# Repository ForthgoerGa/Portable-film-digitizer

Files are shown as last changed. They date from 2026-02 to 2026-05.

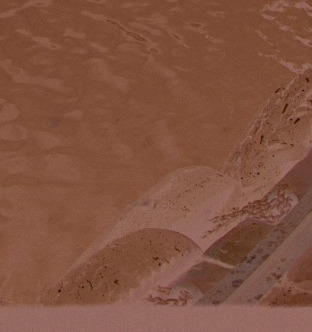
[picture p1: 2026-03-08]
Image_integration&Post_Processing/Negative_example/norway_split_40_overlap/tile_r05_c06_38.png

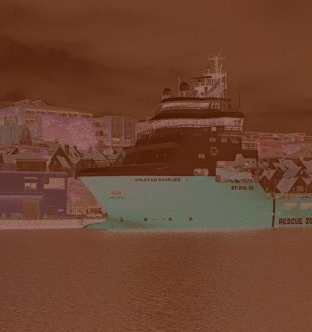
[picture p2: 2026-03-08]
Image_integration&Post_Processing/Negative_example/norway_split_40_overlap/tile_r03_c04_20.png

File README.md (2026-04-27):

# Portable Multi-Format Film Digitization System

ECE 445 coursework design project repository for hardware/firmware/software development and lab notebook tracking.

屏幕截图 2026-04-27 164834

Results:

2026_04_27_00_14_IMG_3069

## System Block Diagram
This block diagram shows the general system design and how the power subsystem, control unit, and imaging subsystem are connected.

Gemini_Generated_Image_8ml5k58ml5k58ml5

## Project Goal
Build a portable, battery-powered film digitizer that supports:
- 35mm negatives/slides (transmissive)
- 120 medium format film (transmissive)
- Instax Mini prints (reflective)

The system captures a raw frame, uploads via Wi-Fi, performs cloud processing (negative inversion + enhancement), and returns a social-media-ready image.

## Problem
Current film digitization workflows are either:
- expensive and slow (professional scanners),
- fast but complex and non-portable (DSLR scanning rigs),
- or outsourced with long turnaround times (lab services).

This project targets a one-click workflow with fast turnaround and practical portability.

## Solution Overview
An STM32-based control system coordinates:
- dual-mode illumination (backlight for transmissive film, angled front light for reflective media),
- high-resolution sensor capture,
- network upload to cloud backend,
- return of processed output to a mobile device.

## Major Subsystems
1. **Power Supply and Management (PCB)**  
   Li-Ion battery pack, charging/protection (BMS), regulated rails for logic and LEDs.
2. **MCU and Control (STM32F4/H7)**  
   UI handling, capture sequencing, sensor interface, and network orchestration.
3. **Dual-Mode Illumination**  
   High-CRI transmissive array + glare-controlled reflective array, PWM-controlled.
4. **Cloud Processing Pipeline (Python)**  
   Negative inversion (orange mask handling), denoising, sharpening, and API response.

## Optical Stack (Current Plan)
- Sensor: Raspberry Pi HQ Camera (IMX477)
- Lens: 25mm f/1.4 C-mount lens
- Extension: 10mm C-mount tube for macro working distance (~8.5 cm)

## Success Criteria
- Resolution: at least `3840 x 2160` output.
- Speed: under `15 seconds` from capture press to phone delivery (stable network).
- Versatility: works with 35mm, 120, and Instax Mini.
- Portability: under `30 cm x 20 cm x 15 cm`, under `1.5 kg`.
- Battery: at least `360 shots` (~10 rolls) per charge.

## Repository Layout
```text
hardware/              PCB + mechanical design files
firmware/              STM32 firmware and drivers
software/              Cloud/image-processing code and APIs
docs/                  Specs, architecture, plans, reports
lab-notebook/          Dated engineering logs
```

## Lab Notebook Workflow
1. Add one file per workday in `lab-notebook/` using `YYYY-MM-DD.md`.
2. Record decisions, measurements, failures, and next steps.
3. Include links to commits, issues, and test data where possible.
4. Use `lab-notebook/TEMPLATE.md` for consistency.

## Quick Start (Local)
```powershell
git init -b main
git add .
git commit -m "Initial project scaffold"
```

## Running the Software

### Web Inspection Server (PC)
Runs the FastAPI server with the web UI for scan control and image review:
```bash
cd software && python server.py
# FastAPI at http://localhost:8000, web UI at http://localhost:8000/web/
```

### Raspberry Pi Camera Server
Streams a live MJPEG preview, triggers captures, and forwards to the PC pipeline:
```bash
# On the Raspberry Pi:
python3 software/rpi_camera_server.py [--port 8080] [--button-pin 17] [--pc-host <PC_IP>]
# Web UI at http://<pi-ip>:8080/
```

### Agentic Post-Processing Pipeline
Runs the Gemini-powered agent loop (classify → process → evaluate → refine):
```bash
cd Agentic_Post_Processing
python orchestrator.py --input-dir data --output-dir output --max-iter 2
```
Requires a `.env` file with `GEMINI_API_KEY` (see `.env.example`). Falls back to heuristics automatically if the key is absent.

### Raw Negative Pipeline (direct)
```bash
python software/processing/negative_pipeline.py \
  --tiles-dir "Image_integration&Post_Processing/Negative_example/norway_split_40_overlap" \
  --output-dir "Image_integration&Post_Processing/output_demo" \
  --wb-clip-percent 0.5
```

## GitHub Setup
See `docs/github-setup.md` for:
- creating the remote repo,
- pushing `main`,
- inviting collaborator `Allannn-sudo`.

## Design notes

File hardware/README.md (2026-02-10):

# Hardware

Hardware design workspace.

## Contents
- `pcb/`: schematics, layout, BOM, manufacturing files
- `mechanical/`: enclosure/chamber CAD and drawings

## Suggested Milestones
1. Define system-level electrical interfaces.
2. Complete power + illumination prototype board.
3. Validate thermal behavior and uniformity.
4. Finalize integrated revision for demo.

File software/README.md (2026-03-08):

# Software

Cloud and processing software.

## Responsibilities
- Receive uploaded raw captures
- Invert color negatives and remove orange mask
- Denoise/sharpen and apply color look
- Return processed image URL/API response

## Suggested structure
- `cloud/`
- `api/`
- `processing/`
- `tests/`

## Current demo
- `processing/negative_pipeline.py`: stitches overlapping film tiles, then restores color with white balance, contrast/tone recovery, and selective cast suppression.
- `server.py` + `web/`: FastAPI + web UI flow where `Start Scan` processes sample fractions, shows tile grid, stitched raw image, and white-balanced output.

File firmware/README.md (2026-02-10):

# Firmware

STM32 firmware workspace.

## Responsibilities
- Capture sequencing and timing
- LED illumination control (PWM)
- Sensor interface and frame acquisition
- Wi-Fi module communication
- UI handling (buttons + OLED)

## Suggested structure
- `src/`
- `include/`
- `drivers/`
- `tests/`

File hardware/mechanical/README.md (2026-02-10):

# Mechanical

Place enclosure and optical chamber models here.

## Suggested structure
- `cad/`
- `drawings/`
- `prints/`
- `assembly-notes/`

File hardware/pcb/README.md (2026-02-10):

# PCB

Place PCB design files here.

## Suggested structure
- `schematics/`
- `layout/`
- `bom/`
- `gerbers/`
- `test-results/`

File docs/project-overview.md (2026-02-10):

# Project Overview

## Summary
Portable film digitization device using an STM32 MCU, dual-mode illumination, and a cloud processing pipeline to deliver fast, social-media-ready images from 35mm, 120, and Instax formats.

## Objectives
- Provide a one-click digitization workflow.
- Achieve 4K output with acceptable dynamic range for common color negative film.
- Maintain portability and low power consumption.

## Scope
- Hardware platform (power, illumination, controller, sensor integration)
- Firmware control and capture pipeline
- Cloud processing prototype for image enhancement
- Lab notebook documentation for engineering decisions

## Key Risks
- Illumination uniformity and glare control
- End-to-end latency under variable network conditions
- Reliable negative inversion across different film stocks

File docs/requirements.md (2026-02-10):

# Requirements and Verification

## Functional Requirements
1. Capture and process at least three formats: 35mm, 120, Instax Mini.
2. Produce output image at or above 3840x2160.
3. Complete capture-to-delivery under 15 seconds on stable Wi-Fi.
4. Run from battery power without external adapter during use.
5. Provide user feedback for idle/capture/upload/success/error states.

## Physical Requirements
1. Overall size under 30 cm x 20 cm x 15 cm.
2. Mass under 1.5 kg.
3. Film carrier insertion must be tool-free.

## Power Requirements
1. Support at least 360 captures on one full charge.
2. Maintain stable illumination intensity during low battery.

## Verification Plan
- Resolution: test chart capture and measured pixel dimensions.
- Dynamic range: evaluate shadow/highlight retention on Portra 400 negative sample.
- Latency: timestamp each stage over at least 30 trials.
- Versatility: run end-to-end workflow for all three formats.
- Battery: execute continuous capture run to count total completed shots.

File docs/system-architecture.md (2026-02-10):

# System Architecture

## Block-Level Flow
1. User inserts film carrier and selects mode (or auto-detect).
2. STM32 configures illumination profile and sensor capture parameters.
3. Sensor captures raw frame.
4. Wi-Fi module uploads frame + metadata to cloud endpoint.
5. Cloud function processes image and returns result URL.
6. Device/app displays completion status.

## Hardware Subsystems
- Power subsystem: Li-Ion battery, charger/protection, logic and LED rails.
- Control subsystem: STM32, UI inputs, OLED status output.
- Imaging subsystem: CMOS sensor and lens stack.
- Illumination subsystem: transmissive + reflective arrays, PWM-driven.
- Networking subsystem: Wi-Fi module interface.

## Software Subsystems
- Embedded firmware state machine for capture orchestration.
- Cloud API receiver and storage.
- Image processing pipeline (inversion, denoise, grade).
- Optional mobile/web client for preview and download.

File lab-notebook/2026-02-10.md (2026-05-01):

# 2026-02-10

## Project Kickoff
- Defined problem: portable, multi-format film digitizer with instant cloud-processed output.
- Selected STM32 MCU + IMX477 sensor with dual-mode illumination system.
- Chosen optical stack: 25mm C-mount lens + 10mm extension for macro distance.

## Next Steps
- Draft high-level block diagram.
- Define power budget and battery capacity.
- Identify LED array requirements (CRI, intensity, diffusion stack).

## High-Level Requirements (HLRs)
- 1. Resolution & Quality: The system must be capable of digitizing various film formats (35mm, 120 medium format, and Instax), outputting images with a minimum resolution of 4K (3840x2160). It must possess sufficient dynamic range to recover shadow and highlight details from the negatives. (Design Basis: Utilizing the Pi HQ Camera + 25mm lens + extension tube macro solution + stitching scan technology.)
- 2. Portability & Autonomy: The system must be a self-contained, portable device with physical dimensions limited to 30cm x 20cm x 15cm and a weight of less than 1.5kg. It must be powered by a lithium-ion battery, capable of scanning at least 10 rolls of film (360 exposures) on a single charge.
- 3. Speed & Automation: The system must implement automated lighting adjustment, film transport, and image capture workflows. The total duration from the moment the user presses "Capture" to receiving the processed digital image (via Wi-Fi upload and processing) must not exceed 15 seconds.

## Subsystem Requirements
### A. Power Supply
- **Requirement:** The Power Management Unit (PMU) must convert the 3S Li-Po battery (11.1V) input into three physically isolated voltage rails:
  - **5.0V (≥ 3A):** Stable logic supply for the Raspberry Pi and STM32.
  - **6.0V (≥ 3A):** Dedicated high-current rail for driving servo motors.
  - **12V (Constant Voltage):** For the LED illumination system.
- **Target:** During motor stalls or high-load events, logic circuit voltage fluctuations must not exceed **±5%**, preventing system resets.

### B. Control Unit
- **Requirement:** The control system must employ a **Master–Slave Dual-Core Architecture**:
  - **STM32 (MCU):** Acts as the low-level hardware controller, responsible for reading user inputs and generating PWM signals for precise motor positioning and LED brightness control.
  - **Raspberry Pi (SBC):**  Acts as the high-level co-processor, communicating with the STM32 via USB/UART. It is responsible for driving the HQ Camera for image acquisition and executing data uploads via Wi-Fi.
- **Target:** This architecture fulfills the course’s assessment requirements regarding “low-level hardware design skills.”

### C. Imaging & Illumination
- **Requirement:** The system must integrate an **IMX477 12MP sensor** (paired with a 25mm lens and 10mm extension tubes for macro focusing) and a **dual-mode LED array** (high-CRI backlight for negatives and reflective light for photo paper). The system must automatically switch light sources based on media type and provide uniform, flicker-free illumination.

### D. Motion System
- **Requirement:** The motion system must utilize multiple **Hitec HS-318 standard servos**, providing at least **3.7 kgf·cm** of stall torque at **6.0V**. These will drive the film carrier or sensor platform for **sub-millimeter precision positioning** on the X–Y axes to support multi-frame stitching and automatic film winding.

Block_Diagram

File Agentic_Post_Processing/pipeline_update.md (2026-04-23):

# IMX447 RAW Film Pipeline Update Design

## 1. Purpose

This document defines an implementation-facing redesign of the film post-processing pipeline for `Agentic_Post_Processing`.

The new pipeline targets Raspberry Pi HQ Camera IMX447 RAW input and separates:
- technical inversion, which should be physically grounded and diagnostically stable
- aesthetic rendering, which should improve appearance without hiding inversion failures

The first-class workflow assumes these inputs:
1. one flat-field RAW scan containing only the light source
2. one frame RAW scan containing film border / clear base and full image content

Optional future support for a dedicated leader scan is included, but the pipeline must work without it.

## 2. Design goals

### Goals

- Support RAW-aware processing for IMX447 captures
- Use flat-field correction to remove illumination and optical bias before inversion
- Automatically detect film border from the frame scan
- Extract border pixels and estimate film base / orange mask automatically
- Support inversion without a dedicated leader scan
- Optionally improve calibration with a leader scan later
- Keep stage outputs inspectable for diagnostics and agentic orchestration
- Separate technical inversion from final rendering
- Keep module boundaries explicit so future agent-based orchestration can reason about failures by stage

### Non-goals

- Perfect film-stock-specific color reproduction in the first implementation
- Replacing all downstream editing workflows
- Training a learned model in the first version
- Implementing a full GUI redesign in this document
- Requiring a leader scan for the baseline workflow

## 3. Input protocol

### Required inputs

#### A. Flat-field RAW
A RAW image captured with the same hardware and scan configuration, but without film in the optical path.

Requirements:
- same camera
- same lens / magnification
- same ISO
- same exposure time
- same light source intensity and geometry
- same holder / optical stack when possible

Purpose:
- estimate illumination field
- correct shading and color bias from the capture system

#### B. Frame RAW
A RAW image of a real negative frame that includes:
- full photo content
- visible film border or clear base region
- preferably some non-image border area

Purpose:
- estimate per-frame film base / orange mask
- perform inversion of the actual image content

### Optional inputs

#### C. Leader RAW
A dedicated calibration frame with both clear base and heavily exposed dark negative region.

Purpose:
- estimate density endpoints more reliably
- improve D-min / D-max calibration consistency across frames

## 4. High-level end-to-end pipeline

The proposed end-to-end pipeline is:

1. RAW ingest
2. Sensor normalization
3. Flat-field model generation
4. Flat-field correction of the frame
5. Border detection and border confidence estimation
6. Film characterization
7. Technical density inversion
8. Positive rendering
9. Diagnostics and evaluator output

The pipeline should explicitly preserve intermediate outputs for inspection.

## 5. Proposed module breakdown

Recommended new module group:

```text
raw_pipeline/
  raw_ingest.py
  sensor_normalization.py
  flat_field.py
  border_detection.py
  film_characterization.py
  density_inversion.py
  rendering.py
  diagnostics.py
  models.py
```

Existing orchestration can later call these modules through the current `agents/` and `orchestrator.py` flow.

## 6. Core data models / dataclasses

Suggested dataclasses in `raw_pipeline/models.py`.

### RawFrame

```python
@dataclass
class RawFrame:
    path: str
    linear_rgb: np.ndarray
    metadata: dict[str, Any]
    black_level: float | np.ndarray | None
    white_level: float | np.ndarray | None
    wb_multipliers: tuple[float, float, float] | None
    sensor_name: str | None
    width: int
    height: int
```

### FlatFieldModel

```python
@dataclass
class FlatFieldModel:
    flat_linear_rgb: np.ndarray
    normalized_flat: np.ndarray
    illumination_map: np.ndarray
    channel_means: tuple[float, float, float]
    valid_mask: np.ndarray | None
```

### BorderDetectionResult

```python
@dataclass
class BorderDetectionResult:
    frame_bbox: tuple[int, int, int, int] | None
    border_mask: np.ndarray
    content_mask: np.ndarray
    clearbase_candidate_mask: np.ndarray
    method_votes: dict[str, float]
    confidence: float
```

### FilmCharacterization

```python
@dataclass
class FilmCharacterization:
    base_rgb: np.ndarray
    base_density_rgb: np.ndarray | None
    upper_density_rgb: np.ndarray | None
    dmin_rgb: np.ndarray | None
    dmax_rgb: np.ndarray | None
    border_confidence: float
    upper_ref_confidence: float
    calibration_mode: str
    notes: list[str]
```

### InversionResult

```python
@dataclass
class InversionResult:
    positive_linear_rgb: np.ndarray
    density_rgb: np.ndarray
    density_norm_rgb: np.ndarray | None
    channel_spread: float
    clipping_ratio: float
    diagnostics: dict[str, float]
```

### RenderResult

```python
@dataclass
class RenderResult:
    rendered_rgb: np.ndarray
    technical_positive_rgb: np.ndarray
    render_metrics: dict[str, float]
```

### PipelineResult

```python
@dataclass
class PipelineResult:
    flat_model: FlatFieldModel
    border_result: BorderDetectionResult
    film_characterization: FilmCharacterization
    inversion_result: InversionResult
    render_result: RenderResult
    evaluator_output: dict[str, Any]
```

## 7. Detailed module interfaces

## 7.1 raw_ingest.py

Purpose:
- read IMX447 RAW files into linear float32 RGB
- preserve metadata needed for reproducibility

Suggested functions:

```python
def load_raw_frame(path: str) -> RawFrame:
    ...
```

Responsibilities:
- use a RAW-capable loader such as `rawpy`
- disable auto-brightening
- keep gamma linear
- preserve metadata fields relevant to calibration

Notes:
- this module should not perform aesthetic color correction
- this module should not apply final white balance for look rendering

## 7.2 sensor_normalization.py

Purpose:
- normalize sensor-domain information before flat-field or film analysis

Suggested functions:

```python
def subtract_black_level(raw: RawFrame) -> np.ndarray:
    ...

def normalize_white_level(image: np.ndarray, raw: RawFrame) -> np.ndarray:
    ...

def apply_bad_pixel_correction(image: np.ndarray) -> np.ndarray:
    ...

def prepare_linear_rgb(raw: RawFrame) -> np.ndarray:
    ...
```

Responsibilities:
- black level subtraction
- white level normalization
- optional bad-pixel correction
- return linear float32 RGB in [0,1] or similarly documented linear range

## 7.3 flat_field.py

Purpose:
- build an illumination correction model from the flat-field RAW
- apply that correction to the frame RAW

Suggested functions:

```python
def build_flat_field_model(flat_rgb: np.ndarray) -> FlatFieldModel:
    ...

def apply_flat_field(frame_rgb: np.ndarray, flat_model: FlatFieldModel) -> np.ndarray:
    ...
```

Responsibilities:
- normalize flat image so global mean is approximately 1
- estimate low-frequency illumination field
- suppress lighting color imbalance and falloff

Expected behavior:
- if `flat_rgb` is spatially uneven, `illumination_map` captures that
- corrected frame should preserve relative scene transmission while reducing system bias

## 7.4 border_detection.py

Purpose:
- automatically find film border / clear base candidates from the frame scan

Suggested functions:

```python
def detect_border_regions(frame_rgb: np.ndarray) -> BorderDetectionResult:
    ...

def projection_based_border_candidate(frame_rgb: np.ndarray) -> tuple[np.ndarray, float]:
    ...

def edge_based_border_candidate(frame_rgb: np.ndarray) -> tuple[np.ndarray, float]:
    ...

def low_variance_border_candidate(frame_rgb: np.ndarray) -> tuple[np.ndarray, float]:
    ...

def merge_border_candidates(candidates: list[tuple[np.ndarray, float]]) -> BorderDetectionResult:
    ...
```

Responsibilities:
- detect likely border area from geometry and image statistics
- avoid relying on an agent for low-level pixel segmentation
- produce a usable border mask and a confidence score

## 7.5 film_characterization.py

Purpose:
- estimate film base and density references from border and scene content

Suggested functions:

```python
def estimate_base_from_border(frame_rgb: np.ndarray, border: BorderDetectionResult) -> np.ndarray:
    ...

def estimate_base_density(frame_rgb: np.ndarray, base_rgb: np.ndarray) -> np.ndarray:
    ...

def estimate_scene_upper_density(frame_rgb: np.ndarray, base_rgb: np.ndarray) -> tuple[np.ndarray, float]:
    ...

def characterize_film(
    frame_rgb: np.ndarray,
    border: BorderDetectionResult,
    leader_rgb: np.ndarray | None = None,
    flat_model: FlatFieldModel | None = None,
) -> FilmCharacterization:
    ...
```

Responsibilities:
- estimate `base_rgb` from stable border pixels
- derive a border-based base density estimate
- if no leader exists, estimate an upper-density reference conservatively from scene data
- if leader exists, prefer leader-based D-min / D-max calibration

## 7.6 density_inversion.py

Purpose:
- perform technically grounded negative inversion using density-domain operations

Suggested functions:

```python
def compute_transmission(frame_rgb: np.ndarray, base_rgb: np.ndarray | None = None) -> np.ndarray:
    ...

def compute_density(transmission_rgb: np.ndarray) -> np.ndarray:
    ...

def subtract_base_density(density_rgb: np.ndarray, base_density_rgb: np.ndarray) -> np.ndarray:
    ...

def normalize_density(
    density_rgb: np.ndarray,
    dmin_rgb: np.ndarray | None,
    dmax_rgb: np.ndarray | None,
    upper_density_rgb: np.ndarray | None,
) -> np.ndarray:
    ...

def invert_negative(
    frame_rgb: np.ndarray,
    characterization: FilmCharacterization,
) -> InversionResult:
    ...
```

Responsibilities:
- convert corrected linear intensities into density-domain representation
- remove base density contribution
- map negative density into normalized positive domain
- expose diagnostics instead of silently hiding unstable behavior

## 7.7 rendering.py

Purpose:
- apply aesthetic rendering after technical inversion is already complete

Suggested functions:

```python
def apply_residual_white_balance(image_rgb: np.ndarray, gains: tuple[float, float, float]) -> np.ndarray:
    ...

def apply_tone_curve(image_rgb: np.ndarray, params: dict[str, float]) -> np.ndarray:
    ...

def apply_color_rendering(image_rgb: np.ndarray, params: dict[str, float]) -> np.ndarray:
    ...

def apply_detail_rendering(image_rgb: np.ndarray, params: dict[str, float]) -> np.ndarray:
    ...

def render_positive(image_rgb: np.ndarray, params: dict[str, Any]) -> RenderResult:
    ...
```

Responsibilities:
- operate only on already-inverted positive data
- avoid hiding inversion-stage failure
- keep rendering parameters distinct from technical inversion parameters

## 7.8 diagnostics.py

Purpose:
- generate stage-aware diagnostics for agentic orchestration

Suggested functions:

```python
def evaluate_border_result(border: BorderDetectionResult) -> dict[str, float]:
    ...

def evaluate_characterization(characterization: FilmCharacterization) -> dict[str, float]:
    ...

def evaluate_inversion(inversion: InversionResult) -> dict[str, float]:
    ...

def evaluate_render(render: RenderResult) -> dict[str, float]:
    ...

def build_evaluator_output(
    border: BorderDetectionResult,
    characterization: FilmCharacterization,
    inversion: InversionResult,
    render: RenderResult,
) -> dict[str, Any]:
    ...
```

Responsibilities:
- produce stage-specific confidence and failure signals
- support agentic retry logic
- support strategy changes, not only slider tuning

## 8. Border detection and border confidence strategy

The border detector should be automatic.

The preferred approach is CV-first, not agent-first.

The initial implementation should combine at least three candidate methods:
- projection-based boundary estimation
- edge/line-based boundary estimation
- low-variance edge-region detection

The detector should produce:
- `border_mask`
- `content_mask`
- `clearbase_candidate_mask`
- `confidence`

### Confidence heuristics

Confidence should increase when:
- multiple methods agree on a similar border region
- border pixels have low variance
- border pixels have color consistency across multiple sides
- border region is spatially contiguous and located near image edges

Confidence should decrease when:
- different sides produce inconsistent base estimates
- estimated border contains strong texture or scene content
- candidate border region is too small
- candidate border colors vary strongly after flat-field correction

## 9. Film characterization without leader, and optional leader-enhanced mode

### Why border-only estimation is useful

Border / clear base estimation provides a strong estimate of:
- film base color
- orange mask contribution
- D-min-like lower reference behavior

This is already much better than estimating film base from scene highlights.

### Why border-only estimation is not equivalent to full leader calibration

Border-only estimation typically gives one reliable endpoint: the base side.

It does not reliably provide the upper density endpoint of the negative. Scene content may not contain a stable or representative darkest-density region, so estimating the upper bound from image content can drift between frames.

Therefore:
- border-only mode is useful and should be first-class
- border-only mode is not equivalent to explicit D-min / D-max calibration

### Baseline mode: no leader

In the default workflow without a leader scan:
- estimate `base_rgb` from border / clear base pixels
- derive `base_density_rgb`
- estimate `upper_density_rgb` conservatively from scene content using robust density statistics
- set `calibration_mode = "border_plus_scene_estimate"`

### Enhanced mode: leader available

If a dedicated leader scan is provided:
- estimate clear base from leader clear area
- estimate heavily exposed density from leader dark area
- derive `dmin_rgb` and `dmax_rgb`
- set `calibration_mode = "border_plus_leader"`

Leader-enhanced mode should override unstable scene-based upper-density estimation.

## 10. Density inversion strategy

The inversion core should operate in a density-aware way.

Suggested conceptual flow:

1. start from flat-field-corrected linear RGB
2. derive transmission proxy
3. convert to density using a log transform
4. subtract base density contribution
5. normalize density using border-derived or leader-derived references
6. map normalized density into positive linear RGB

The initial implementation should expose intermediate arrays for debugging:
- corrected frame
- border sample visualization
- density image
- normalized density image
- technical positive result

## 11. Technical inversion vs aesthetic rendering

This separation is mandatory.

### Technical inversion stage

Technical inversion is responsible for:
- raw-aware ingestion
- flat-field correction
- border extraction
- base estimation
- density transform
- density normalization
- initial positive reconstruction

This stage should aim for:
- physical plausibility
- consistency across frames
- diagnostic transparency

### Aesthetic rendering stage

Rendering is responsible for:
- residual white balance refinement
- tone shaping
- contrast
- saturation / vibrance
- sharpening
- optional look presets

This stage should not be used to hide systematic inversion failures.

If technical inversion fails, evaluator output should flag technical failure rather than compensating with aggressive rendering.

## 12. Diagnostics / evaluator outputs for agentic orchestration

The evaluator should move from a single final-image score toward stage-aware diagnostics.

Suggested output structure:

```python
{
  "overall_score": float,
  "stage_scores": {
    "border_detection": float,
    "film_characterization": float,
    "technical_inversion": float,
    "rendering": float,
  },
  "cast_type": str | None,
  "suspected_failure_stage": str | None,
  "recommended_strategy": str | None,
  "recommended_params": dict[str, Any],
  "confidence": float,
  "notes": list[str],
}
```

Suggested `suspected_failure_stage` values:
- `flat_field`
- `border_detection`
- `film_characterization`
- `density_inversion`
- `rendering`

Suggested `recommended_strategy` values:
- `retry_border_detection_projection`
- `retry_border_detection_low_variance`
- `use_conservative_upper_density`
- `use_leader_calibration`
- `reduce_render_strength`
- `increase_border_weight`

## 13. Suggested implementation phases and acceptance criteria

### Phase 1: RAW ingest + flat-field

Deliverables:
- `raw_ingest.py`
- `sensor_normalization.py`
- `flat_field.py`

Acceptance criteria:
- IMX447 RAW files load reproducibly
- flat-field correction reduces visible low-frequency illumination bias
- corrected frame is stable across repeated runs

### Phase 2: Border detection + base estimation

Deliverables:
- `border_detection.py`
- partial `film_characterization.py`

Acceptance criteria:
- border mask is extracted automatically on representative scans
- border confidence correlates with obvious success/failure cases
- base estimate is more stable than full-frame brightest-pixel estimation

### Phase 3: Technical inversion core

Deliverables:
- `density_inversion.py`
- remaining `film_characterization.py`

Acceptance criteria:
- technical positive output is visibly less biased than the current heuristic demasking pipeline
- blue cast frequency is reduced on representative test images
- intermediate density diagnostics are saved or inspectable

### Phase 4: Rendering stage

Deliverables:
- `rendering.py`

Acceptance criteria:
- rendering can improve appearance without changing technical inversion internals
- technical output and rendered output can be compared side by side

### Phase 5: Diagnostics and agentic orchestration

Deliverables:
- `diagnostics.py`
- orchestration integration

Acceptance criteria:
- evaluator can identify likely failure stage
- retries can choose between strategies, not just scalar parameter changes

## 14. Risks and open questions

### Risks

- Border may be partially missing or contaminated by scene content
- Scene-based upper-density estimation may drift on low-contrast frames
- RAW decoding choices may affect density calibration consistency
- IMX447-specific metadata availability may vary by capture path
- Flat-field reference may become invalid if scan geometry or lighting changes

### Open questions

- Should demosaic happen before or after some parts of normalization, or should a Bayer-domain correction path be preserved?
- Should the initial implementation support only DNG-compatible RAW files, or multiple raw formats?
- Should border detection work on full-resolution data or on a proxy with later mask upsampling?
- Should film characterization store per-side base estimates to diagnose asymmetry explicitly?
- At what point should stock-aware profiles or learned correction models be introduced?

## 15. Immediate implementation recommendation

For the first implementation pass, prioritize:
1. IMX447 RAW ingest
2. flat-field correction
3. automatic border detection
4. border-based base estimation
5. density inversion without leader
6. diagnostics for border confidence and blue-cast detection

Leader support should be added next as a calibration enhancement, not as a prerequisite for the baseline pipeline.

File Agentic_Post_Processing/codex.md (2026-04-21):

# raw_pipeline update summary

Date: 2026-04-14
Project: `C:\ece_445\Agentic_Post_Processing`

## What was implemented / improved

This round focused on turning `raw_pipeline/` from a broad first-pass scaffold into a more internally consistent RAW-aware negative pipeline prototype.

### 1. Density / reference semantics were corrected

Files updated:
- `raw_pipeline/models.py`
- `raw_pipeline/film_characterization.py`
- `raw_pipeline/density_inversion.py`

Main fixes:
- Removed the earlier logical mismatch where the pipeline computed relative transmission as `frame / base`, converted it to density with `-log(frame / base)`, and then effectively handled base offset a second time.
- Unified calibration semantics so downstream normalization works with density-space references rather than mixing linear-RGB and density representations.
- `normalize_density()` now accepts density-space references directly:
  - `upper_density_rgb`
  - `dmin_density_rgb`
  - `dmax_density_rgb`

Effect:
- The inversion path is now mathematically more self-consistent.
- Clear base is treated as the zero/reference point in the intended relative-density space.

### 2. Border detection was pushed toward film-specific geometry

File updated:
- `raw_pipeline/border_detection.py`

Main fixes:
- Kept the original three-cue candidate generation:
  - projection-based
  - edge-based
  - low-variance-based
- Added a refinement stage after generic voting:
  - keep only edge-connected connected-components
  - convert resulting candidates into top / bottom / left / right border strips
  - compute confidence partly from side-strip coverage rather than only generic vote agreement

Effect:
- Final `border_mask` is now closer to film-border geometry instead of an arbitrary fragmented pixel mask.
- Internal false-positive regions are less likely to survive into characterization.

### 3. Base estimation was upgraded from simple percentile to stable clear-base selection

File updated:
- `raw_pipeline/film_characterization.py`

Main fixes:
- Replaced the simple “take border pixels and compute a percentile” approach with a more robust selection process:
  - start from `clearbase_candidate_mask`, fallback to `border_mask`
  - keep brighter border candidates
  - reject pixels with larger inter-channel spread
  - choose a more stable bright cluster
  - use median of the selected cluster as `base_rgb`
- Added side-wise estimation:
  - split usable border candidates into `top`, `bottom`, `left`, `right`
  - estimate a base RGB for each usable side
  - fuse only mutually consistent sides
  - drop inconsistent side estimates when needed

New characterization fields:
- `base_sample_count`
- `base_rel_spread`
- `side_consistency_score`
- `side_base_rgbs`

Effect:
- `base_rgb` is less likely to be dominated by a contaminated border region, local leak, or content intrusion.
- The pipeline now surfaces whether different sides of the frame agree on the base estimate.

### 4. Diagnostics were made more physically useful

Files updated:
- `raw_pipeline/diagnostics.py`
- `raw_pipeline/pipeline.py`
- `raw_pipeline/density_inversion.py`

Main additions:
- Characterization-side metrics:
  - `base_sample_count`
  - `base_rel_spread`
  - `side_consistency_score`
  - side estimate count
  - density span
- Inversion-side density distribution metrics:
  - `density_p50_mean`
  - `density_p95_mean`
  - `density_p99_mean`
  - `density_p99_spread`
  - `density_headroom`
  - `headroom_score`
- `pipeline.py` stage metrics now serialize the new characterization outputs, including `side_base_rgbs`.

Effect:
- The pipeline is now better at exposing whether failure is due to border detection, base estimation, or density normalization.
- This is especially important before real IMX447 sample intake.

## Smoke test run status

A full end-to-end smoke test was run through the public entrypoint:
- function: `process_raw_negative(...)`
- frame input: `data\sample1.jpg`
- flat input: `data\sample3.png`
- output dir: `output\raw_pipeline_smoke`

Important note:
- This was **not** a real RAW validation run.
- The project did not contain ready-to-use RAW samples, so the test used the JPEG/PNG fallback path in `raw_ingest.py`.
- Therefore this confirms **entry-flow executability and diagnostics behavior**, not final physical correctness for IMX447.

### Smoke test result

Status:
- pipeline completed successfully
- returned `status: ok`
- saved intermediates:
  - `01_flat_corrected.png`
  - `02_border_mask.png`
  - `03_technical_positive.png`
  - `04_density_norm.png`
  - `05_rendered.png`

Observed metrics of note:
- `border_confidence = 0.5921`
- `base_sample_count = 30083`
- `base_rel_spread = 1.29772`
- `side_consistency_score = 0.65485`
- fused side estimates from: `top`, `left`
- inconsistent side estimates were dropped
- `clipping_ratio = 0.82653`
- `clipped_white_ratio = 0.82147`

Interpretation:
- The pipeline runs end-to-end without crashing.
- The new diagnostics correctly expose that this fallback sample run is still heavily over-bright / upper-clipped.
- This is acceptable for now because these are non-RAW fallback images and not the intended calibration protocol.
- More importantly, the pipeline is now instrumented enough that when real IMX447 samples arrive, we should be able to tell whether the next issue is caused by:
  - bad border/base estimation
  - inconsistent side estimates
  - poor upper-density estimation
  - normalization / clipping behavior

## Gateway and decision-model integration update

The stable Gemini-based agentic pipeline should remain the default fast path.
This round therefore shifted from replacing Gemini to adding an optional
high-level decision path that uses a stronger OpenAI-compatible gateway model.

Files updated:
- `config.py`
- `agents/gateway_model.py`
- `agents/decision_model.py`
- `orchestrator.py`
- `.env.example`
- `readme.md`

### What changed

1. Preserved the stable Gemini defaults
- `MODEL_PROVIDER` now defaults back to `gemini`
- `VLM_MODEL` and `LLM_MODEL` default back to `gemini-2.5-flash`
- Existing classifier/evaluator fast path remains the main pipeline

2. Added an optional gateway-backed decision model
- New config flags:
  - `DECISION_MODEL_ENABLED`
  - `DECISION_MODEL`
  - `DECISION_MODEL_GROUP`
  - `DECISION_SCORE_TRIGGER`
  - `DECISION_MIN_ITERATION`
- New module:
  - `agents/decision_model.py`
- Intended role:
  - high-level strategy / escalation only
  - not the default fast path
  - not a replacement for the stable Gemini loop

3. Added orchestration hook for difficult cases
- `orchestrator.py` now accepts an optional `DecisionAgent`
- If enabled, it may override the next iteration's parameter suggestion only when:
  - current iteration >= `DECISION_MIN_ITERATION`
  - current score <= `DECISION_SCORE_TRIGGER`
  - the regular fast path has not already passed

4. Added gateway transport support
- `agents/gateway_model.py` sends text + image multimodal requests through an OpenAI-compatible endpoint
- Intended base URL pattern:
  - `https://yinli.one/v1`

### Model probing result for the first gateway key pattern

Tested successfully through:
- `https://yinli.one/v1/chat/completions`

Models that returned valid minimal completions:
- `gpt-4o-mini`
- `gpt-4.1-mini`
- `gpt-4.1`
- `deepseek-chat` (backend surfaced as `deepseek-v3`)

User-provided gateway screenshots additionally confirmed that the gateway also exposes stronger model families, including:
- `gpt-5-chat-latest`
- `gpt-5-mini`
- `gpt-5-pro`
- `gpt-5.1-chat`
- `gpt-5.2`

The agreed direction is to use:
- existing Gemini path for the main fast/rollback loop
- a tiered higher-level decision stack aligned to measured stability:
  - primary: `gpt-5-mini`
  - fallback: `gpt-5.1-chat`
  - expert: `gpt-5-pro`

### Recommended environment setup

Create `C:\ece_445\Agentic_Post_Processing\.env` with a layout like:

```env
# Stable Gemini main path
MODEL_PROVIDER=gemini
GEMINI_API_KEY=your_existing_stable_gemini_key
VLM_MODEL=gemini-2.5-flash
LLM_MODEL=gemini-2.5-flash

# Optional escalation-only decision model
DECISION_MODEL_ENABLED=1
OPENAI_API_KEY=your_gateway_key
OPENAI_BASE_URL=https://yinli.one/v1
DECISION_MODEL=gpt-5-mini
DECISION_MODEL_GROUP=
DECISION_MODEL_FALLBACK=gpt-5.1-chat
DECISION_MODEL_FALLBACK_GROUP=
DECISION_MODEL_EXPERT=gpt-5-pro
DECISION_MODEL_EXPERT_GROUP=
DECISION_SCORE_TRIGGER=0.55
DECISION_MIN_ITERATION=2

MAX_EVAL_ITERATIONS=3
QUALITY_THRESHOLD=0.75
```

### Where to place the formal key

Do **not** hardcode it into source files.
Place the real key in one of these:
- project `.env`
- machine/user environment variables
- OpenClaw secret/config environment if this project is run under OpenClaw

For this project specifically, the simplest path is:
- create `C:\ece_445\Agentic_Post_Processing\.env`
- populate it from `.env.example`

## Current assessment

The system now has three meaningful layers:
- stable Gemini main path
- optional stronger tiered high-level decision path via gateway (`gpt-5-mini` / `gpt-5.1-chat` / `gpt-5-pro`)
- experimental RAW-aware `raw_pipeline/`

This preserves the current working pipeline while preparing a stronger escalation route for difficult images and future real-sample debugging.

## Recommended next step

Next step should be intake of real Raspberry Pi HQ Camera IMX447 sample data using the agreed protocol:
- one flat-field RAW scan
- one frame RAW scan containing border / clear base / full image
- optional leader RAW scan

When real samples are provided, inspect first:
- `base_rgb`
- `side_base_rgbs`
- `side_consistency_score`
- `base_rel_spread`
- `upper_density_rgb`
- `clipping_ratio`
- saved intermediate outputs under the smoke/output directory

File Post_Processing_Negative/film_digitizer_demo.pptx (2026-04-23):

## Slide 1

Film Digitization System

Software Pipeline: Scan · Stitch · Post-Process

ECE 445 · Raspberry Pi HQ Camera (IMX477) · STM32 MCU · Gemini AI

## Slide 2

OVERVIEW

Software Pipeline Architecture

01

SCAN

RPi HQ Camera captures overlapping tiles; STM32 steps motorized film gate on each exposure

02

STITCH

Feather-blend 40 tiles into a seamless full-frame mosaic using manifest-driven weight maps

03

PROCESS

Density-domain negative inversion + perceptual tone mapping + Gemini-driven iterative refinement

04

OUTPUT

Social-media-ready JPEG + metadata JSON report; cloud upload via AWS S3 + Lambda

Hardware: STM32 MCU controls dual LED arrays (backlight / frontlight) and motorized film gate

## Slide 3

STAGE 01 — SCANNING

Tile Capture & Coordination

40-tile capture grid (5 × 8)

1

Browser sends POST /scan → FastAPI server.py triggers job

server.py

2

ScanJobCoordinator starts background thread; state machine: Ready → Working

coordinator.py

3

STM32 steps film gate; RPi HQ Camera captures each tile (IMX477, 12 MP)

serial_comm.py · MockSerialInterface fallback for dev

4

Each tile saved with row/col position metadata to manifest.csv

tiles/ + manifest.csv

← overlap region (feather zone)

5

Frontend polls GET /status at 500 ms; receives state + output URLs on done

software/web/app.js

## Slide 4

STAGE 02 — STITCHING

Feather-Blended Tile Assembly

Weighted Pixel Accumulation

- Overlap zone: linear weight ramp ε → 1.0 → ε
- Non-overlap zone: weight = 1.0
- output = Σ(pixel × weight) / Σ(weight) → seamless seams

Weight profile across tile boundary:

Tile 1

Tile 2

ramp

Tile 3

ramp

manifest.csv Schema

row, col, filename, left, top, right, bottom, overlap_x_px, overlap_y_px
Tile positions define exact pixel placement on the full-frame canvas

weight = 1.0

ramp

weight = 1.0

ramp

weight = 1.0

← Tile A · Overlap · Tile B · Overlap · Tile C →

Output Files

- stitched_raw.png
- inverted_positive.png
- white_balanced.png · leveled.png
- desaturation_mask.png
- processed_negative.png ← final

Post-Stitch Enhancement Stages

- Invert (255 − pixel)
- White Balance (per-channel percentile gain)
- Auto-Levels → CLAHE (LAB L-channel)
- Cast-suppression mask → Selective Desaturation
- Unsharp Mask (σ=1.2, amount=0.35)

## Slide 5

THE CORE CHALLENGE

Why Negatives Are the Hardest Problem

Orange Mask

- Film base has a deep orange coupler dye
- Varies by brand, age, and chemistry
- Must be estimated from clear-base ROI
- Incorrect removal destroys color accuracy

Inverted Tones & Dye Crosstalk

- Cyan/Magenta/Yellow dyes record complements
- Simple 255−x inversion creates severe casts
- Dye channels bleed into each other
- Must invert in optical-density space

Non-linear Tone & Gamma

- Film gamma ≠ digital display gamma
- Shadow/highlight zones behave non-linearly
- Perceptual tone mapping required (LAB)
- Auto-levels alone → flat, desaturated result

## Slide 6

STAGE 03 — NEGATIVE INVERSION

Density-Domain Inversion Pipeline

①

Base
Correction

frame ÷ base_rgb
clips transmission
to (ε, 1]

②

Density
Calc

density =
−log(transmission)
per channel

③

Dye
Unmixing

3 × 3 matrix
separates CMY
dye channels

④

Expm1
Invert

(eˣ − 1) ×
gains
[1.35, 1.20, 1.10]

⑤

Color
Mapping

gray anchor +
empirical 3×3 +
neutral damp

Key Insight: Optical Density Space

- OD = −log(light transmission through film)
- Dye concentrations add linearly in OD (Beer-Lambert)
- Preserves color relationships across exposures
- Simple RGB inversion breaks this — OD space fixes it

Conservative Dye Unmixing Matrix

[ 1.55 −0.38 −0.17 ]
[ −0.22 1.44 −0.22 ]
[ −0.08 −0.45 1.53 ]
Blended with identity matrix by strength

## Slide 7

STAGE 03 — PHYSICAL RAW PIPELINE

RAW-First 10-Stage Correction

RAW Bayer Ingest

rawpy loads .dng; extracts Bayer mosaic + black/white level metadata → float32

DNG

Dye Unmixing

3×3 matrix in density domain blended with identity; separates CMY channels

S5

Flat-Field Correction

Multi-scale Gaussian models backlight illumination map per CFA plane; corrected = frame ÷ illum^strength

S1

Expm1 Inversion

(eˣ − 1) × per-channel gains [1.35, 1.20, 1.10] → positive image

S6

Demosaic → RGB

Bilinear Bayer interpolation → linear float32 RGB; diagnostic preview saved

Soft Reference Mapping

Gray anchor (0.35) → empirical 3×3 → neutral damp → red guard; 3 presets

S2

S7

Base Reference Extraction

Median RGB of clear-base ROI (p10–p90 luma) from reference_layout.json

S3

Perceptual Tone + Color Ref

LAB zoned tone curve; pseudo-LUT hue/chroma adjust; neutral-region protection

S8+

Base Correction + Density

frame ÷ base_rgb → transmission; −log(T) → optical density; percentile normalize

S4

Final Finish & Export

sRGB OETF; exposure/contrast/temp/tint; grain + bloom + sharpening → PNG + JSON report

OUT

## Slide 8

STAGE 03 — AGENTIC AI REFINEMENT

Gemini-Powered Iterative Refinement

ClassifierAgent

Film Type Detection

- Gemini VLM → JSON: film_type
- Types: negative_35mm, negative_120, positive_35mm, positive_120
- Fallback: aspect ratio + luma/saturation heuristics

Feedback Loop

PostProcessingAgent

13-Stage Negative Pipeline

- Routes by film type to correct pipeline
- Negative: density inversion → gray-world WB → LAB neutralization → CLAHE → vibrance → unsharp
- Positive: lighter 7-stage pipeline

EvaluatorAgent

Quality Scoring & Param Tuning

- 9 metrics: gray_mean, clipping ratios, channel_spread, saturation, laplacian_variance
- Gemini scores image 0–1 + autonomously tunes 14 parameters
- Loop until score ≥ 0.75 or max iterations reached

Output: <stem>_processed.png + <stem>_meta.json (score, metrics, params, iteration log)

if score < 0.75 → EvaluatorAgent suggests new params → PostProcessingAgent re-runs → EvaluatorAgent re-scores → repeat (max_iter)

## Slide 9

QUALITY ASSURANCE

Evaluator Quality Metrics & 14 Tunable Parameters

gray_mean

Ideal: 100 – 165

Overall exposure level

gray_std

Ideal: > 30

Tonal contrast present

clipped_black

Ideal: < 0.5 %

No crushed shadows

clipped_white

Ideal: < 0.5 %

No blown highlights

blue_red_delta

Ideal: ≈ 0

Color balance neutral

channel_spread

Ideal: < 0.10

No dominant color cast

mean_saturation

Ideal: 0.08 – 0.45

Natural color richness

14 Autonomously Tuned Parameters:

laplacian_var

Ideal: > 150

Image sharpness proxy

quality_score

Ideal: ≥ 0.75

Gemini VLM composite grade

wb_clip_percent · black_point · white_point · clahe_clip · clahe_grid · unsharp_amount · unsharp_sigma · desat_strength · shadow_lift · gamma · lab_strength · highlight_compression · vibrance · desat_sigma

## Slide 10

TECHNICAL SUMMARY

From Film to Feed

40

tiles

feather-blended into
seamless mosaic

10+

stages

physically-grounded
RAW pipeline

14

params

tuned autonomously
by Gemini VLM

9

metrics

exposure, color,
sharpness, clipping

Scan → tile capture via RPi + STM32 Stitch → feather-blend 40 tiles Process → density inversion + AI refinement

ECE 445 · Film Digitization System · Post-Processing Team

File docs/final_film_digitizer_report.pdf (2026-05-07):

# PORTABLE FILM DIGITIZER

By

### Yuhong Chen

### Guyan Wang

### Arnav Gaddam

Final Report for ECE 445, Senior Design, Spring 2026

TA: Gerasimos Gerogiannis

06 May 2026

Project No. 23

ii

### Abstract

This is a report detailing the design of a device built to convert analog film to a digital format using raster scanning and a computer vision processing pipeline.

The film digitizer system is a standalone device that uses an onboard Raspberry Pi 4 computer and Sony IMX477 camera to move row-by-row and capture several high-fidelity images of negative and positive film. Following the scanning step, computer vision algorithms are used to stitch macro frames together and apply further post-processing steps such as denoising and negative inversion. Camera position is controlled by a precision X-Y stage driven by NEMA 17 stepper motors and an STM32 microcontroller. The device exposes a user interface through a web application hosted on the Raspberry Pi, which allows for a completely automated scanning process and digital receipt of final outputs.

iii

### Contents

iv

### 1. Introduction

### 1.1 Problem

In an age where most modern media is captured on devices like cell phones and digital cameras, analog film is harder than ever to distribute. Enthusiasts can use professional drum scanners, flatbed scanners, or manual DSLR scanning to convert their analog captures to digital formats, but these solutions are complex, non-portable, and require expert knowledge.

### 1.2 Solution

We aim to address this with a portable film digitizer, which will allow users to convert their film to a digital format without specialized knowledge or equipment using a raster scanning process. The digitizer will be a fully self-contained device that can perform scans without external power or manual intervention. A high-quality camera is positioned at specific positions over a piece of film, and several captures are stitched together before being processed into an end result.

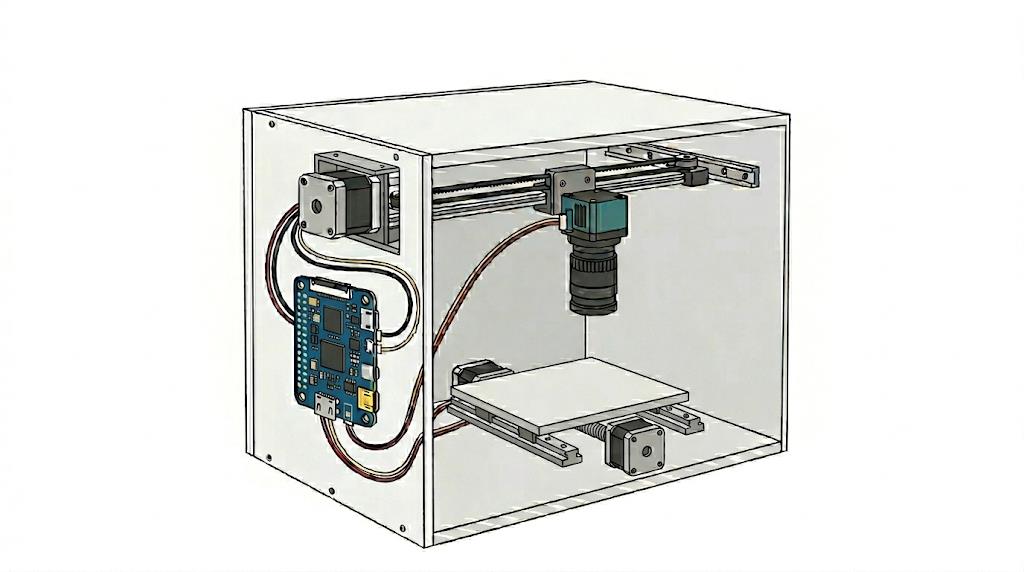
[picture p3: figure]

Figure 1: Prototype Design

### 1.3 High Level Requirements

To quantify the success of this project, we propose the following requirements:

### 1.3.1 Resolution and Stitching

The system must produce a final image with a minimum resolution of 3840x2160 pixels by autonomously moving the camera to capture and stitch at least 4 overlapping macro frames with an alignment error of less than 5 pixels.

### 1.3.2 Portability

The complete device, including power, optics, and mechanical parts, must fit within a physical volume of 15cm (L) X 15cm (W) X 20cm (H) and weigh less than 1.5kg to meet our portability requirements. There should be no reliance on external power, network connection, or specialized equipment for hardware tuning.

### 1.3.3 Automation Speed

The system must complete the full cycle of automatic exposure, X-Y scanning, image capture, and software stitching for a single frame in under 30 seconds without human intervention.

### 2 Design Procedure

The design process for this project involved making different decisions and tradeoffs along the way with respect to physical constraints, engineering challenges, and impact on user experience.

The prototype combines five major subsystems: an imaging subsystem, an illumination subsystem, a motion subsystem, a Raspberry Pi and STM32 scanner/control subsystem, and a cloud processing subsystem. The Raspberry Pi controls camera capture, motion, and lighting. The cloud server owns user-facing job state, API routing, RAW processing, and final artifact storage.

### 2.1 Block Diagram

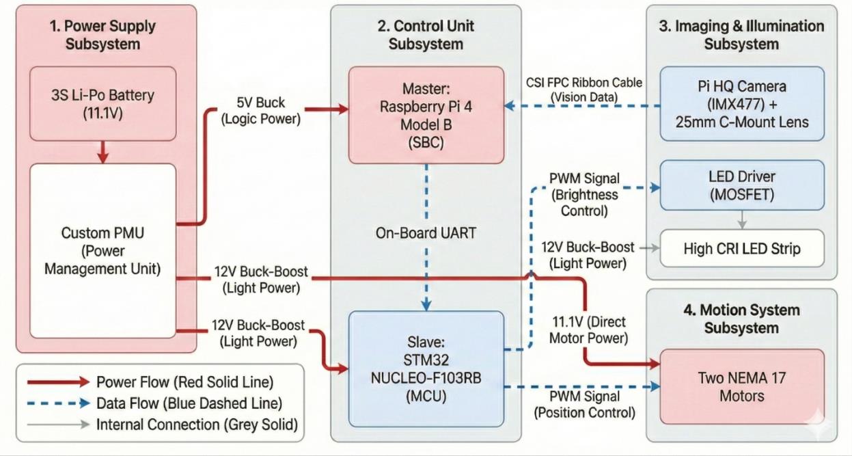
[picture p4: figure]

Figure 2: System Block Diagram

### 2.2 Power Supply and Management

The power subsystem is responsible for allowing the digitizer device to operate without the aid of an external power source or wall outlet in accordance with the portability requirements. This system is comprised of a rechargeable Li-Po battery, charging circuit, and voltage regulators to step down source voltage to the required logic levels.

Motor Driver Current Limiting (A4988)

To ensure our A4988 stepper motor drivers do not draw excessive current and overheat the power system, the maximum current limit (ITripMax) must be set using the on-board potentiometer (VREF)

and the current sense resistor (RS).

(1)

Micro stepping Current: During micro stepping, the internal DAC further reduces this maximum current in precise percentage steps based on the step sequence:
(2)

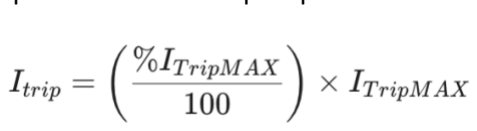
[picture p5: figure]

Fixed Off-Time (toff): Utilizing a resistor on the ROSC pin to ground to set a custom fixed off-time for PWM current control, the duration in microseconds is calculated as:

(3)

Logic Level Trigger Thresholds (VIH)

This equation mathematically proves why our initial testing failed when sending 3.3V logic signals from the Raspberry Pi to the 5V-powered A4988 and WS2812B LEDs. Both components calculate their minimum "High" logic input voltage (VIH) based on their main supply voltage (VDD).

(4)

If VDD is 5V, the minimum trigger voltage is 0.7 * 5 V = 3.5 V. Because the Raspberry Pi outputs exactly

3.3V, it falls short of the 3.5V threshold, necessitating the 3.3V logic supply for the A4988 and the 3.3V-to-5V level shifter for the LEDs.

Voltage Regulator Power Dissipation & Thermal Limits

Our voltage regulation system utilizes linear regulators (AMS1117) to drop voltages for sub-systems; the power dissipation equations are used to ensure the components do not trigger thermal shutdown.

Power Dissipation
(5)

Junction Temperature

(6)

Variables: TA(MAX) is the maximum ambient temperature, and θJA is the package's thermal resistance

from junction to ambient. The maximum junction temperature (TJ
) must never exceed 125°C.

I/O Dynamic Current Consumption

When our Raspberry Pi switches GPIO pins (such as sending the 800Kbps data stream to the WS2812B LEDs), it consumes dynamic current to charge and discharge the capacitive load of the line.

(7)

Variables: ISW is the sunk current, fSW is the I/O switching frequency, and C is the total capacitance of the pin and external trace (CINT + CEXT).

### 2.3 Motion System

The motion subsystem is responsible for accurately positioning the camera module and film stage in two-dimensional space. Due to physical constraints of our mechanical design, we independently control the position of the camera and film. Our camera mounted to the top of the assembly moves along the X axis, while the film stage at the bottom moves along the Y axis. This allows us to physically achieve a full range of motion in the X-Y plane and take captures with the camera centered at any coordinate within the surface of the film.

The main components are two precision translation stages with attached NEMA-17 stepper motors. Rather than controlling the motors directly, our system relies on two A4988 stepper motor drivers to convert digital motor control signals to analog current. GPIO pins on microcontrollers such as the STM32 output 3.3V and are limited to 20mA of current. The NEMA-17 motors we need require at least 12V and over 1A per phase [6]. A microcontroller cannot physically support this, which is why we decided to use motor drivers [3].

Another advantage of using motor drivers is the capability to perform micro stepping. Directly controlling a motor only allows full or half steps of rotation. However, motor drivers like the A4988 have internal circuitry to allocate current between motor coils, which allows each physical motor step to be split into 16 parts. This offers much greater control and smoothness, which is crucial for our project since even small perturbations in camera displacement can have drastic impact on macro frame captures.

Dstep – Linear displacement per microstep
P – Lead screw pitch (mm/rev) = 2 mm
Srev – Full steps per motor revolution = 200 steps M – Microstepping factor = 16

V – Linear velocity (mm/s)
f – Step frequency (Hz)

Npulses – Total number of pulses issued ΔL – Target displacement (mm)
(8)

Dstep =

P

Srev × M

=

2

### 32 mm/step

(9)

### V = f × Dstep

Npulses =

∆L

Dstep

(10)

Observing the equations, it can be seen that linear displacement ΔL is a function of the number of pulses issued to the motor driver. The speed at which this displacement is achieved is a linear function of step frequency. By doubling the frequency, which is the same as halving the interval between steps, the speed of motion is doubled. By changing the duration and frequency of a square wave, a control signal can manipulate the displacement and speed achieved by each motor.

### 2.4 Imaging and Illumination

The imaging system consists of a high-quality camera and 25mm lens used to capture clear images at a distance of 8.5 cm from the film [2]. An LED backlight array will be used to provide illumination for negative film, with brightness being controlled with pulse-width modulation from the control system to support multiple film densities. A separate frontlight LED array will be fixed to the upper side of the device to illuminate positive and Instax film. One major change made to this system after initial design was to use an off-the-shelf LED light for backlight capabilities.

### 2.5 Processing Pipeline

In addition to onboard computer vision processing on the Raspberry Pi used in the design, we will also employ cloud resources where appropriate to accelerate compute-intensive post processing tasks. This mainly consists of negative inversion, denoising, sharpening, and any additional steps such as LLM-augmented generation. The algorithms will be executed as Python scripts running in a serverless environment on a cloud provider such as Amazon Web Services to keep costs low and have minimal off-device dependencies [4].

We designed our pipeline to be modular and able to be partitioned between the Raspberry Pi and cloud environment. This is a tradeoff that users can make depending on what level of cloud dependency they prefer. For example, the pipeline can be configured to run entirely on device, but at the cost of a few minutes of real-world time due to the weaker hardware. Meanwhile, the opposite case would be performing only the stitching algorithm locally and then offloading the more intensive steps to the cloud

[7]. Depending on user preference and network conditions, the pipeline can run for a varying duration with various capabilities.

Table 1: API Endpoints and Capabilities

Interface | Endpoint or route | Verified role
Browser to Cloud | POST /api/jobs | Creates a user-facing scan or processing job.
Browser to Cloud | GET /api/jobs/{job_id} | Returns state, progress, artifacts, and errors.
Browser to Cloud | GET /api/jobs/{job_id}/artifacts/raw or final | Serves browser-safe raw preview and final result artifacts.
Browser to Cloud (dev) | /api/dev/* | Provides development capture, calibration, and status tools.
Cloud to Pi | POST /scan/start | Starts Raspberry Pi scan sequence.
Cloud to Pi | GET /scan/status | Reports scan state, tile progress, and errors.
Pi to Cloud | /internal/jobs/{job_id}/receive_tile | Uploads per-tile DNG/JPG captures for processing.

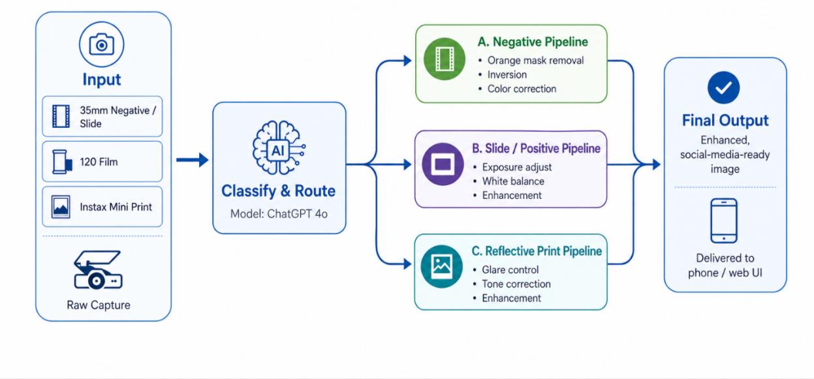
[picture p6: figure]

Figure 3: Post-Processing Overview

### 2.6 Control Unit

The control unit is responsible for integrating the other subsystems together and serving as the interface between device and user. The main components of this subsystem are a Raspberry Pi computer, STM32 microcontroller, and the software applications running to manage user interfaces and hardware interaction.

When designing this system, there were multiple approaches to component selection and defining integration points. The simplest way would be to only use a microcontroller without the presence of a Raspberry Pi computer. This would still allow for coordination of motor movement with camera captures but would need an additional persistent storage medium like an SD card. One frame capture would take about 18.5 MB, which is an entire order of magnitude greater than the 512 KB of on-chip flash memory of a standard microcontroller such as the STM32f446re [5]. One workaround for this would have been to use directory memory access (DMA) to directly transfer captures to an SD card, which would not involve the microcontroller CPU at all.

Resolution: 4056 x 3040 pixels
Bit Depth: 12-bit RAW

### Total Pixels × Bits/Pixel

8

= 18.5 MB

(11)

However, another issue with this approach is that all capture post-processing would need to be offloaded to cloud compute resources, as standard microcontrollers do not have the processing power or memory capacity to efficiently handle several large frames. In addition to adding a dependence on network availability, this would also greatly impact latency as each capture would need to be uploaded at full resolution.

Stotal – data transfer size
Sraw – size of single capture Sproc – size of processed output N – number of frames
BW – network speed in Mbps
Stotal = (N × SRaw) + SProc = 320.9 MB | (12)

Tnetwork =

Stotal × 8

### BW = 256.72 seconds

(13)

Network transfer alone would take around 4 minutes, which would be the fastest possible completion time for the processing step, which excludes the physical scanning process. A better approach was to incorporate a Raspberry Pi into the project, as this provided a complete solution for capture storage, coordination, and processing. Having a full computer available allows for complete local processing, without a need for network connectivity or complex peripheral interactions with the camera module.

Another reason we used the Raspberry Pi was for the ability to expose a control interface over a local wireless network without the need for an internet connection. This allows users to use any client device such as a laptop or mobile phone to access the scanner’s control interface in the browser and start scanning.

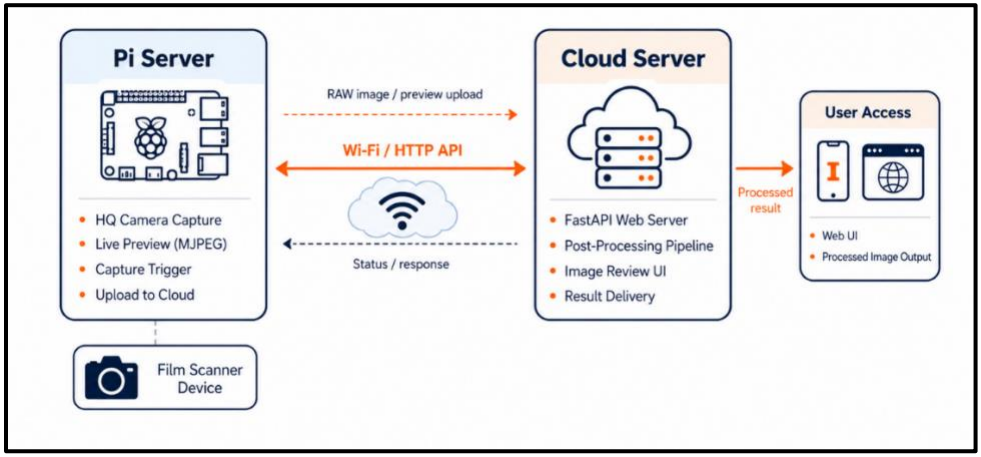
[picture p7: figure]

Figure 4: Software Architecture

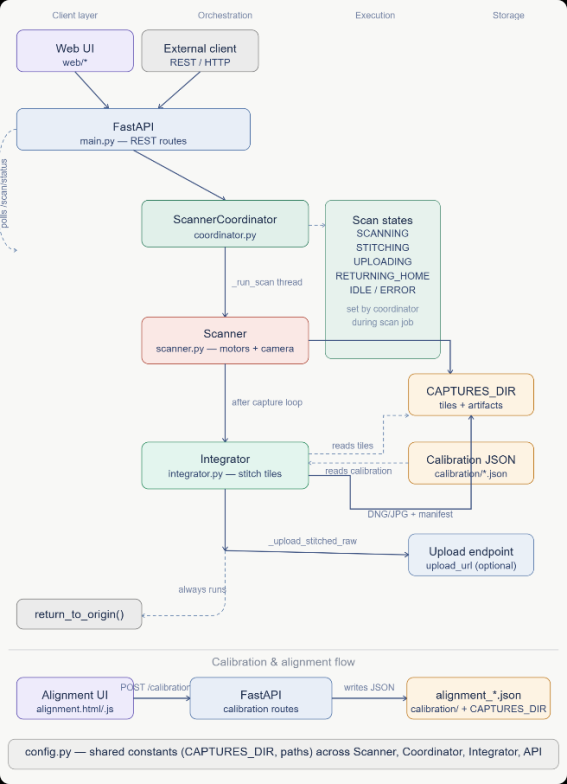
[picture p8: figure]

Figure 5: Control Flowchart

### 3 Design Verification

### 3.1 Power Supply and Management

To verify the power supply system we independently tested components in isolation. The circuit takes as input 11.1 V from a lithium-polymer battery and steps it down to 5V and 3.3V. The first step in verification was to charge the battery, then connect it to the power rail of a breadboard and verify with a multimeter that the reading was within the expected range. Then, we checked the output of the 5V regulator module and AMS1117 3.3V regulator the same way. An oscilloscope reading was also taken to ensure that voltage spikes from the battery and capacitor system did not have an impact on the interpretation of logic signals.

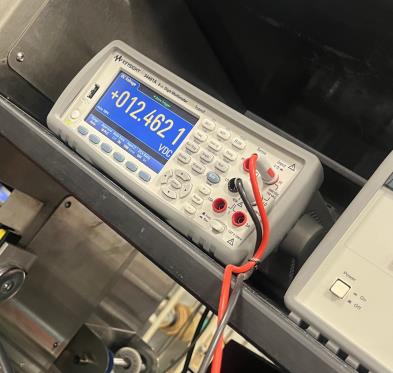
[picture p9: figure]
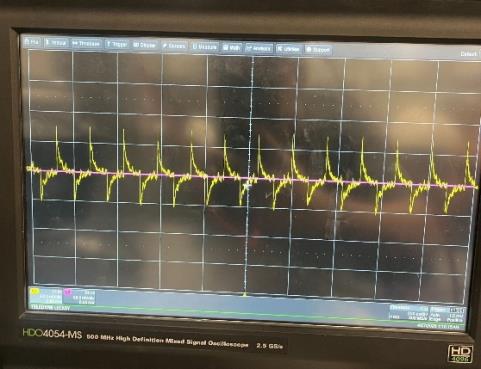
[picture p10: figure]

Figure 6: Battery Voltage Reading | Figure 7: Logic Signal Voltage Ripple Reading

### 3.2 Motion, Illumination, and Imaging

To verify the motion and imaging subsystem, a bench power supply was used in place of the battery and voltage regulators. The setup for this used two output voltages: one at 11V and another at 5V. An A4988 motor driver was installed on a breadboard according to the circuit schematic, with the appropriate control pins wired HIGH or LOW. Two GPIO pins of an STM32 development board were connected to STEP and DIR pins on the driver, and the four output pins were connected to stepper motor coils.

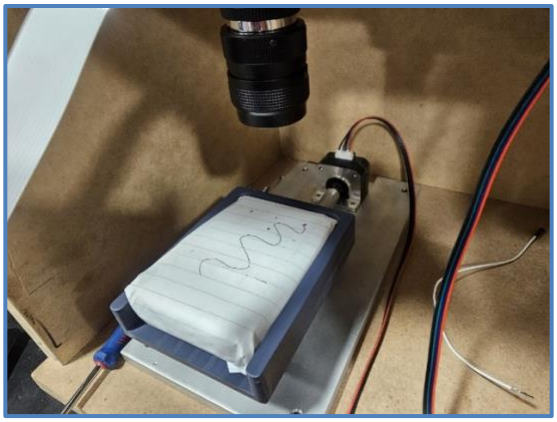
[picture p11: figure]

Figure 8: Calibration Test

### 3.3 Processing Pipeline

The final output requirement was at least 3840 x 2160 pixels using overlapping macro frames. The final system met this requirement. The scanner captured a calibrated multi-frame sequence, and the integrated output was suitable for 4K display. The stitching requirement also specified no visible discontinuities and alignment error within 5 ±1 pixels. Test scans using textured/grid-like targets showed continuous features across tile boundaries after calibration and overlap refinement.

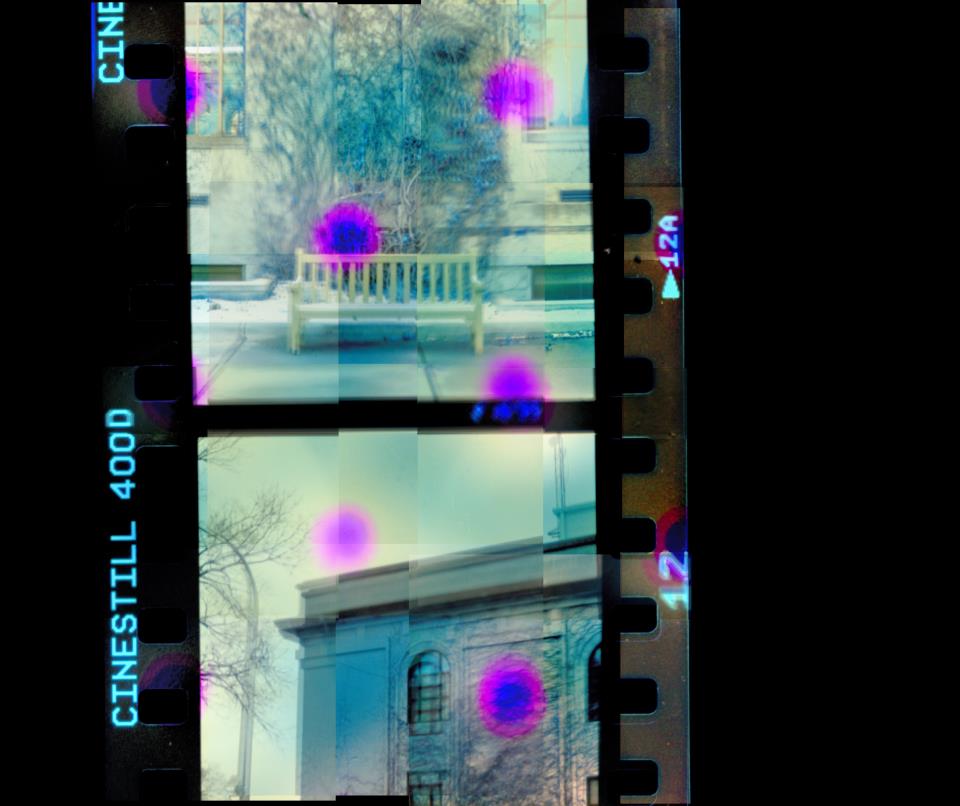
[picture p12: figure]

Figure 9: Processed Negative Film

The negative processing sub requirement was met. The fastest preview path runs in less than 1 second, the RAW fast preview path takes 1 to 3 seconds per tile, and the full high-quality negative RAW pipeline meets the less than 30 seconds per-image target. The complete mechanical scan and process cycle still exceeds 30 seconds, so the original full-cycle speed target is marked partially met rather than fully met.

### 3.4 Control Unit

Table 2: Processing Latency

Mode | Input/output | Typical latency | Use
Simple inversion/direct preview | JPEG/PNG preview to preview image | < 1 s | Fast UI/debug path; low quality.

RAW fast preview | Single DNG tile to RGB preview | about 1 to 3s per tile | Classification and base-region detection.
Full negative RAW pipeline | Single DNG tile to corrected output | < 30s per tile | High-quality negative processing path.

The API requirement was verified by sending scan commands to the Raspberry Pi controller process and receiving uploaded image artifacts and processed result URLs on the server [10]. The current implementation supports per-tile DNG/JPG upload and retains a legacy stitched-RAW route for compatibility, but the preferred final path is per-tile upload.

### 4. Costs

### 4.1 Parts

Table 3: Part Costs

Item | Vendor | Quantity | Unit Cost ($) | Total Cost ($)

Power & Control Subsystem

12V 2400mAh AA NI-MH Battery | ECE Supply Center | 1 | 0.17 | 0.17
SPST 20A On-Off Toggle Switch | ECE Supply Center | 1 | 4.27 | 4.27
PCB Mount Fuse Holder 5x20mm | ECE Supply Center | 1 | 0.80 | 0.80
IRF520 MOSFET N-Channel | DigiKey | 1 | 3.00 | 3.00
10K Ohm 10 Watt Resistor | ECE Supply Center | 1 | 0.75 | 0.75
DFR0379 Voltage Regulator 20W | DigiKey | 1 | 4.90 | 4.90
AMS1117 Linear Voltage Regulator | DigiKey | 1 | 0.12 | 0.12
SWD 0.05" 10-Pin SMT Box Header | DigiKey | 1 | 1.50 | 1.50
Capacitors (1µF, 4.7µF, 3.3pF) | Online Purchase | 1 ea. | Var. | 0.35

Motion & Automation

NEMA 17 Stepper Motor | StepperOnline | 2 | 4.43 | 8.86
Allegro A4988 Stepper Driver | DigiKey | 2 | 6.95 | 13.90

Illumination System

High-CRI LED Strip | Amazon | 1 | 14.99 | 14.99
High-CRI LED Plate | Amazon | 1 | 12.99 | 12.99

Optical & Vision System

Raspberry Pi HQ Camera (12MP) | Adafruit | 1 | 55.00 | 55.00
Fujian 25mm f/1.4 C-Mount Lens | Amazon | 1 | 19.54 | 19.54
25mm 5mm Extension Tube | Amazon | 2 | 4.99 | 9.98
15CM FFC Cable | Amazon | 1 | 6.99 | 6.99
| | | Total Estimated Cost $158.11

### 4.2 Labor

Table 4: Labor Costs

Member | Primary contribution area | Weeks Worked | Hours / Week | Total Cost
Guyan Wang | Hardware, power, mechanical, verification support | 14 | 10 | $8,400
Yuhong Chen | PC/Pi software integration, processing pipeline, web/API, documentation | 14 | 10 | $8,400
Arnav Gaddam | Raspberry Pi scanner control, motor/camera server, scan calibration | 14 | 10 | $8,400
Machine Shop | Mechanical design and assembly | 2 | 5 | $700
Student Hourly Rate: $60/hr Machine Shop Hourly rate: $70/hr | | | Total Cost: $25,900

Table 5: Labor Schedule

Week Of | Task | Group Members
2/9 | Finalize component selection | All
| Draft STM32 pinout | Allan
| Define UART serial protocol | Arnav
| Setup AWS cloud environment | Arnav
2/16 | Complete schematic and PCB layout | Allan
| Setup STM32 IDE project and test GPIO | Arnav
| Setup Raspberry Pi OS and remote access | Leo
2/23 | Submit 1st round PCB order after finishing layout | Allan
| Write PWM logic for LED control and STEP/DIR for motors | Arnav
| Create a self-hosted control plane UI on Raspberry Pi | Leo, Arnav
3/2 | Order mechanical parts and lab equipment | Leo
| Experiment with software tradeoffs before design review | Leo, Arnav
| Develop image inversion and cropping algorithm | Leo
3/9 | Prepare a circuit for breadboard demo | Arnav, Allan
| Demonstrate motor movement through STM32 MCU | Arnav, Allan
3/16 | Begin soldering components onto PCB | Arnav, Allan
| Optimize processing pipeline end to end latency | Leo
3/23 | Hardware testing and debugging for power system | Allan
| Integrate Raspberry Pi camera with control software | Arnav
3/30 | Test motors and LEDs under load | Allan
| Continue soldering components, testing incrementally | All
4/6 | Demonstrate stable power delivery and voltage regulation | Allan
| Demonstrate image capture and negative inversion step | All

4/13 | Optimize motor acceleration profiles to avoid skipped steps | Arnav
| Optimize image resolution and color correction | Leo
4/20 | Verify physical power limits and motor current | Allan
| Work on presentation slides | All
| Continue to debug physical motion and system integration | All
4/27 | Debug integration before final demo | All
| Finalize requirements and verification results | All
| Make software robust for demo | Leo, Arnav
5/4 | Work on final presentation | All
| Lab equipment check out | All

### 5. Conclusion

### 5.1 Accomplishments

The project produced a working macro-stitching film digitizer prototype. The final system captures overlapping film tiles with a Raspberry Pi camera and motorized stage, uploads per-tile RAW artifacts to a PC server, performs RAW-based correction and film processing, and integrates processed tiles into a final image. The system met key final-system requirements: 4K-class output, more than the minimum number of overlapping frames, seam alignment within 5 ±1 pixels, automated API upload/result flow, motion control, return-to-home behavior, regulated power, and GPIO-controlled illumination.

### 5.2 Uncertainties

The main unsatisfactory results were physical portability and full-cycle latency. The final prototype exceeded the original size/mass target, and the complete scan plus processing cycle exceeded the original 30 s target. The positive-film color pipeline also needs more tuning; the negative pipeline is more mature because it received more debugging time with real film data.

### 5.3 Ethical considerations

The project involves battery-powered electromechanical motion, bright illumination, and image data handling. Safety risks were mitigated by using regulated power rails, avoiding motor commands outside configured bounds, and keeping debug controls explicit. Privacy risk is limited because captured images are locally generated film scans, but future cloud deployment should avoid uploading user images without clear consent and should protect API keys and stored artifacts. These practices align with the IEEE Code of Ethics emphasis on public safety, honest reporting, and protection of privacy [1].

In accordance with the IEEE Code of Ethics [1], our team has identified and mitigated several ethical and safety concerns associated with the Portable Film Digitizer.

Public Safety and Health: We have prioritized safety regarding the 3S Li-Po battery design by integrating a Battery Management System to prevent overcharging and fire risks. Additionally, all mechanical pinch points created by the NEMA 17 motors are enclosed within the device housing to prevent user injury.

Disclosure and Honesty: We acknowledge the use of open-source libraries, specifically OpenCV [7] and libcamera, and do not claim their algorithms or code as our own work.

Intellectual Property and Misuse: We recognize that high-speed digitization could assist the unauthorized copying of copyrighted photographs. While the hardware cannot prevent this by itself, our user documentation and instructions will explicitly warn users only to digitize content that they own or have permission to use.

Environmental Responsibility: By repurposing precision X-Y linear stages and utilizing LED illumination, we aim to minimize electronic waste and energy consumption.

### 5.4 Future work

Future work should improve the positive-film color pipeline, reduce mechanical size and mass, add formal ISO 12233 chart measurements, and optimize scan latency through faster motion profiles and parallel capture/upload/processing. One major physical improvement is to switch to a closed-loop design for motor control. The current design has no feedback mechanism to detect missed steps due to inertia or mechanical resistance, causing discrepancies in measured vs expected displacement. An immediate improvement in scan quality could come from integrating rotary encoders into the motion system, which would transmit real-time data back to the controller. The motor control logic on the STM32 microcontroller would shift from pulse generation to a PID loop, allowing for self-correction during the scan. This would reduce the need for frequent manual calibration as well as avoid disruptions due to mechanical issues such as a stuck linear stage.

A cleaner production build should also remove transitional debug routes and package the deployment path for continuous integration with protection against functional regressions and major bugs.

### References

[1] IEEE Code of Ethics, IEEE, 2020. [Online]. Available: https://www.ieee.org/about/corporate/governance/p7-8.html
[2] Raspberry Pi Ltd, "Raspberry Pi High Quality Camera Product Brief," RP-008344-DS, May 2025. [Online]. Available: https://datasheets.raspberrypi.com/camera/high-quality-camera-product-brief.pdf (https://datasheets.raspberrypi.com/camera/high-quality-camera-product-brief.pdf)
[3] Allegro MicroSystems, "A4988 DMOS Microstepping Driver with Translator and Overcurrent Protection," Datasheet, 2020
[4] Amazon Web Services (AWS), "Operating Lambda: Performance optimization – Part 1," AWS Architecture Blog. [Online]. Available: https://aws.amazon.com/blogs/compute/operating-lambda-performance-optimization-part-1/ (https://aws.amazon.com/blogs/compute/operating-lambda-performance-optimization-part-1/)
[5] STMicroelectronics, "STM32F446xC/E Datasheet," DS10693 Rev 10, 2024. [Online]. Available: https://www.st.com/resource/en/datasheet/stm32f446re.pdf
[6] NEMA 17 Stepper Motor Specification Standard, "Standard 1.8 Degree Stepper Motor Performance Data."
[7] Open Source Computer Vision Library (OpenCV), "Image Stitching Algorithms," Version 4.x, 2026. [Online]. Available: https://docs.opencv.org/ (https://www.google.com/search?q=https://docs.opencv.org/)
[8] G. Wang, Y. Chen, and A. Gaddam, "Portable Automated Macro-Stitching Film Digitizer," ECE 445 Design Document, University of Illinois Urbana-Champaign, Spring 2026.
[9] G. Wang, Y. Chen, and A. Gaddam, "Team 23 - Portable Film Digitization System Requirements and Verifications," University of Illinois Urbana-Champaign, Spring 2026.
[10] S. Ramirez, "FastAPI framework documentation." Available: https://fastapi.tiangolo.com/
[11] International Organization for Standardization, "ISO 12233: Photography - Electronic still picture imaging - Resolution and spatial frequency responses," ISO standard.

### Appendix A: Requirement and Verification Table

Table 6: Power Subsystem Requirements and Verification [9]

Requirements | Verification | Status

Power

Regulate 11.1 battery input to 5V± 0.25V for logic components and 12V± 1V for motor drivers under a load of 100mA to 2000mA | Connect battery to input and measure output rails using a multimeter under no load and full-load | X
Isolate motor noise from logic signals using star topology. Voltage ripple should not exceed 50mV peak-to-peek while motors are running. | Use an oscilloscope to measure voltage ripple on logic rail when motors are under peak current draw. | X

Motion

Achieve a minimum translation resolution of 1 mm += 0.5mm per step using Nema-17 motors. | Issue a command to move the motor for a set number of steps (such as 50 or 100). Measure the physical displacement of the linear stage using a caliper and verify that it matches the desired theoretical displacement.
Execute a row-by-row scanning pattern across a film-sized area and verify that the stage returns to the origin position with a maximum variance of 0.25mm. | Confirm that the stage can run through a scan and return to the starting position for a full reset. | X

Imaging and Illumination

Maintain a consistent focal distance of 8.5cm ± 1mm between the lens element and the film surface to ensure high output image quality. | Mount the camera and lens, capturing a test image at the specified distance and visually inspect image clarity. | X
Adjust backlight brightness using PWM and avoid artifacts during image capture. | Capture images at different PWM duty cycles (such as 10%, 50%, 90%) and inspect frames for artifacts or image deformities | X

Post Processing

The serverless compute environment must be able to execute a Python image processing pipeline to perform negative inversion and denoising with sub 30-second latency per image, with a 5-second margin of error. | Make requests to cloud endpoints with raw images and inspect logs to verify that end-to-end latency is below the target threshold. Use a timing library to record end-to-end latency. | X
The server needs to expose an API interface that the Raspberry Pi can use to upload raw camera data and receive the end result. | Perform HTTP Post requests from the Raspberry Pi controller process with sample images. Verify that the service returns a success message upon receipt and a valid URL to the processed output image. | X

Control System

The Raspberry Pi needs to synchronize camera captures through libcamera with motion commands to the microcontroller. It needs to ensure that the stage is stationary during a capture to prevent motion blur. The capture will need to be taken 500ms ± 50ms after the last motor pulse is issued. | Use a logic analyzer to monitor the control signals from the Pi and the pulses issued from the microcontroller to the motors. Verify that the delay between the last pulse and the capture signal is large enough to avoid motion blur. | X
The STM32 needs to interpret serial commands from the Raspberry Pi and generate motor and LED output signals with low latency. The STM32 must issue a motor pulse within 10ms ± 2ms of receiving a completed control command. | Manually issue movement commands through a serial console. Use an oscilloscope to measure the end-to-end transmission time and evaluate against the threshold. | X
The image stitching algorithm on the Raspberry Pi needs to successfully combine multiple overlapping frames into a single 4K (3840x2160) image with no visible discontinuities or alignment errors ( > 5 pixels ± 1 pixel). | Run the capture sequence on a test image (perhaps a printed grid). Inspect the stitched output to visually verify that there are no alignment issues. Use a calibrated ISO 12233 resolution chart and measure pixel offset at stitch boundaries using an image editing tool [11]. | X

### Appendix B: PCB Design

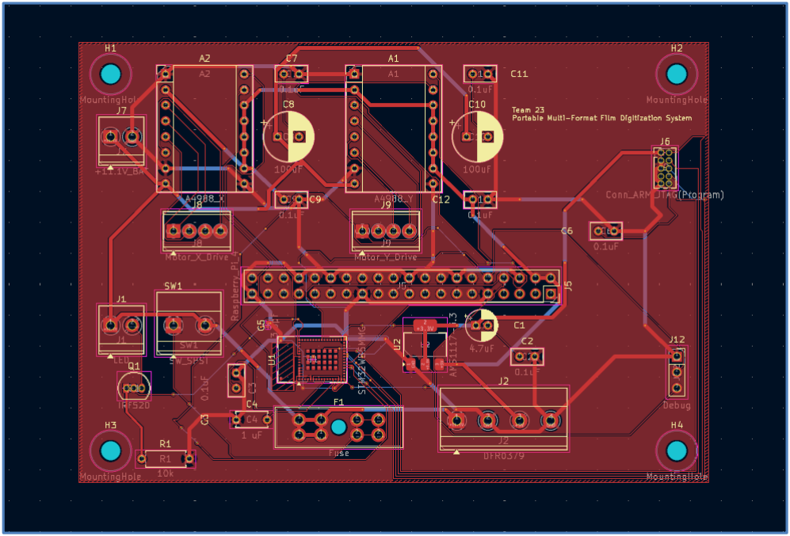
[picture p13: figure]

Figure 10: KiCAD PCB Design

### Appendix C: Circuit Schematic

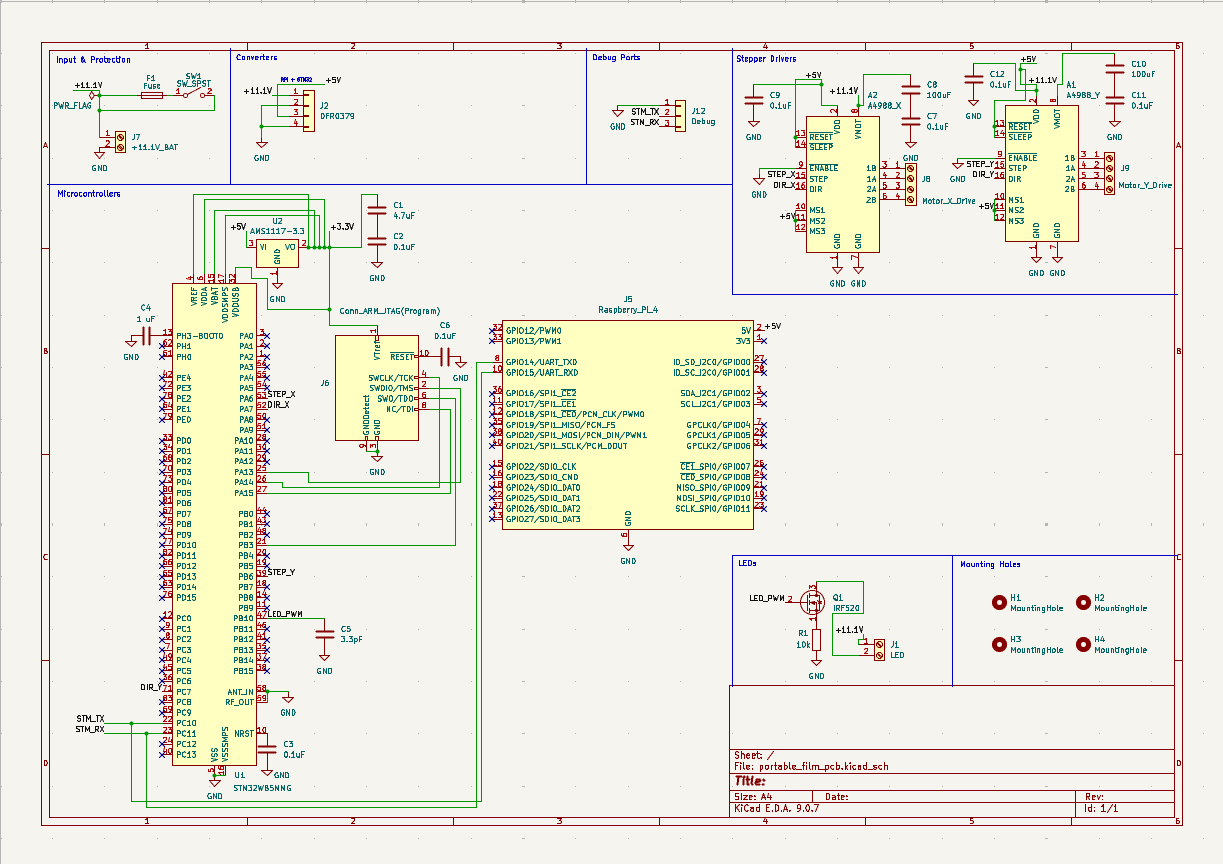
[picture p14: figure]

Figure 11: KiCAD Circuit Schematic

### Appendix D: API and Processing Details

The final deployment uses explicit server roles. The control server normally runs on port 8000 and exposes browser-facing /api/* routes. The Raspberry Pi scanner server normally runs on port 5000 and exposes scan, motion, camera, and calibration routes. IP addresses should be configured explicitly because hotspot/SSH network addresses change between deployments.

The processing path used for the final test is per-tile DNG processing followed by RGB integration. Classification and base-reference bootstrapping use early scan tiles, while later tiles reuse the global classification and base reference. This avoids repeated inconsistent reference estimation and reduces memory pressure compared with processing one synthetic stitched RAW DNG.

Table 7: Processing Parameters

Item | Current setting or evidence needed
Input tile format | Per-tile DNG + JPG/PNG preview from Raspberry Pi camera.
Backlight reference | Matching backlight tile set; insert final calibration folder name.
Flat-field correction | Applied before classification/processing; insert final strength/sigma/max-side settings.
Classification bootstrap | First three tiles for vote; insert model and confidence evidence.
Base reference | Global base color/reference from selected/detected base region; insert final value.
Final integration | Processed RGB tile placement with manual offsets and conservative overlap refinement.

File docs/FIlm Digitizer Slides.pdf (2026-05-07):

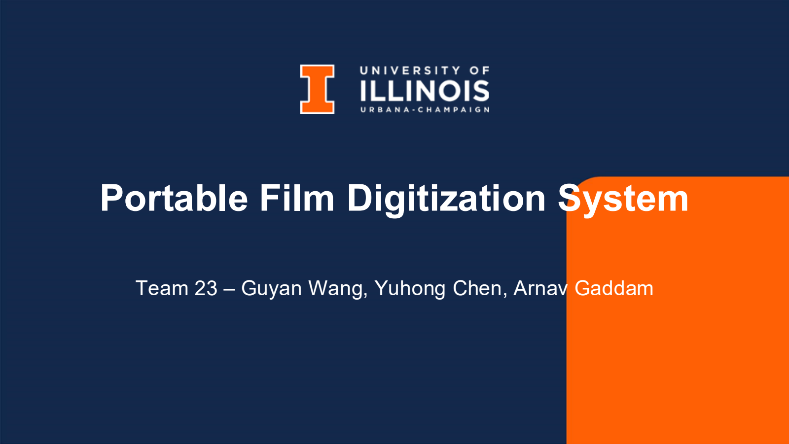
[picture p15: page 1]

# Portable Film Digitization System

## Team 23 – Guyan Wang, Yuhong Chen, Arnav Gaddam

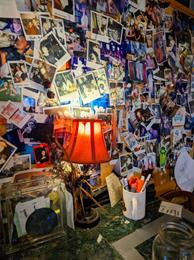
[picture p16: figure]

### Cultural Impact

Analog film is experiencing a resurgence,

### praised for its unique color palette and nostalgic feel—qualities that digital photography struggles to replicate

### Barriers to Access Yet, the complexity of developing and digitizing film is a major hurdle, limiting its accessibility and preventing many from enjoying its full

potential.

## Core Problem

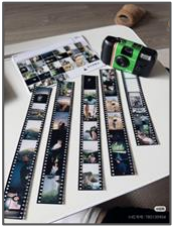
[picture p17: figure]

UNIVERSITY OF ILLINOIS URBANA-CHAMPAIGN | GRAINGER ENGINEERING

## Resurgence of Analog Film Photography

## Core Problem

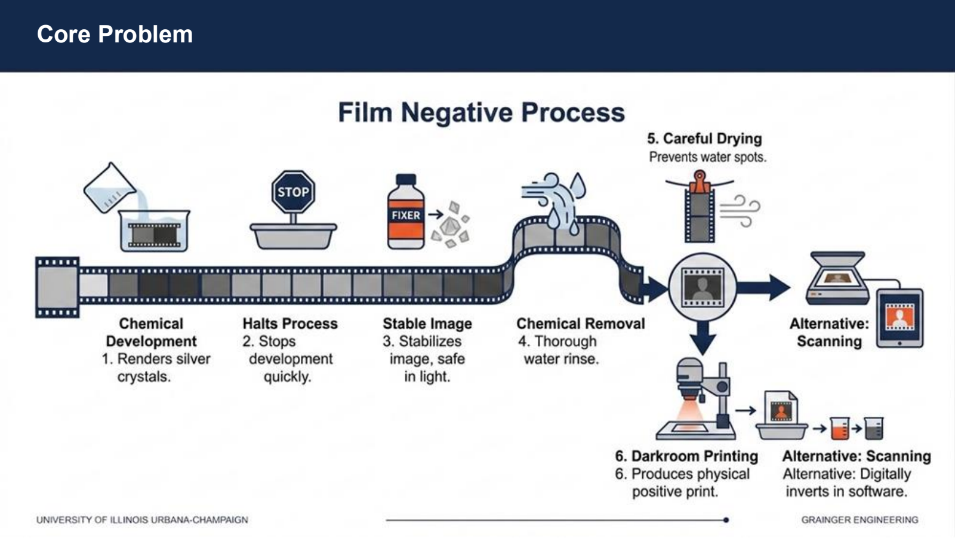
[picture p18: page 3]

## Existing Solution – Instax Film

Remain complex

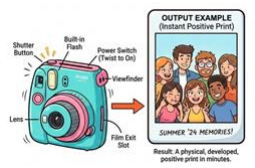
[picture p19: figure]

Core Problem
Existing post processing
pipelines remain complex,
expensive and time
consuming!

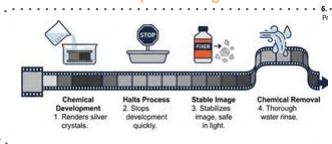
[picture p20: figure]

Preprocessing | Post-Processing (Digitalization)

Professional Scanner

Filml Rephotography set

## Core Problem

## Our Solution: A Portable Digitizer

## Project Objective

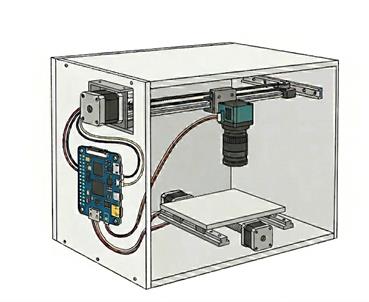
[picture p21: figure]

Prototype Design

### One-Click Automated Scanning

Our device moves a camera over the surface of

analog film to take several high-resolution frame

captures.

We then use a computer vision pipeline to stitch

these frames together into a final, high-quality

digital output.

frame captures with minimal alignment error

## Features and Capabilities

GRAINGER ENGINEERING

## High Level Design

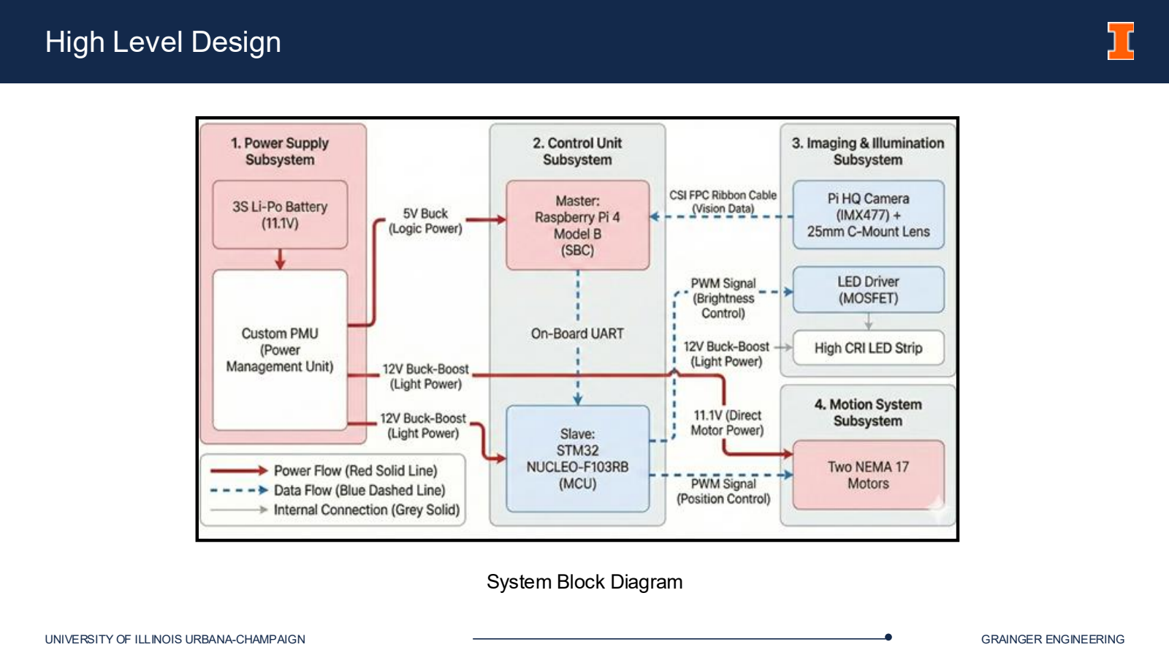
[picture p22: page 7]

CHART / GRAPH

System Block Diagram

## Power Supply System

## Power System Architecture

Core Power & Processing:

- Main Controller Supply
- Battery & Portability
- Voltage Regulation

Sub-System Power Distribution:

- Circuit Input Power (11V)
- Motor Logic Power (5V)
- Lighting Power (5V)

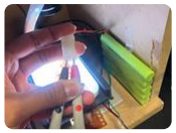
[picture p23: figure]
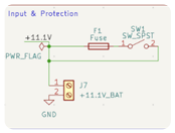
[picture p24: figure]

Battery | Input Schematics

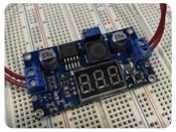
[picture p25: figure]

Converter 1 | Converter 1 Schematics

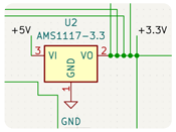
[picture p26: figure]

Converter 2 Schematics

## Power Supply System - Verification

## Power Regulation


Make sure the battery outputs the source voltage the circuit expects

Verification

- Apply battery input
- Measure outputs with multimeter
- Run motors at peak load
- Measure logic rail ripple with oscilloscope
Battery Voltage | Logic Voltage | Voltage Ripple

Error Requirement

- Battery: 12 V ± 1 V (under 100 mA–2 A load)
- Logic: ≤ 5 V ± 0.25 V (under 100 mA–2 A load)
- Logic rail: ≤ 50 mV ripple (peak-to-peak) during operation

## Circuit Verification

## Measured Values

We used lab equipment to verify our circuit on a breadboard and PCB to ensure that the experimental values matched what we expected.


Circuit Prototyping


Raspberry Pi 4 with Circuit

Signal | Value
Battery Input | 12.462 V
Regulated Logic | 5.150 V
Vmot | 11.146 V
Imotor | 0.62 A

## Captures & Smart Lighting

## Imaging and Illumination


High-Fidelity Imaging Setup

- Core Sensor
- Optics
- Macro Adaptation

Dual-Mode Illumination

- Transmissive Media (Negatives & Slides)
- Reflective Media (Instax Prints)
- Automated Control

Smart LED Strip

LED Pad

LED Schematics

## Focal Distance Control

Maintain appropriate lens to film distance for image clarity

Verification

- Mount camera + lens
- Capture test image at target distance
- Check image sharpness (visual)

## Backlight PWM Control

Ensure no image artifacts

Verification

- Capture images at 10%, 50%, 90% duty cycles
- Inspect frames for artifacts/distortion

## Imaging and Illumination - Verification

Error Requirement

- Lens to film distance: 8.5 cm ± 1 mm
- PWM control: Adjust
brightness via PWM
without introducing
artifacts

Distance between lens and film

10% duty cycle | 50% duty cycle | 90% duty cycle

## Precise 2D Motion

We have stepper motors in 2 planes: X and Y. We need to coordinate the movement of both motors to get accurate captures of specific coordinates within the film.

Control Interface:

Raspberry Pi → STM32 → Motor Driver → Motor Coils

- We use motor drivers to control motor speed and direction via digital logic
- Raspberry Pi issues high level commands to MCU over serial
- MCU GPIO pins output STEP and DIR signals
- STEP frequency controls motor speed, DIR controls direction

## Scanning System


Scanning System Components

## Motor Drift

Even small movement errors result in drastic image capture errors.

Requirement and Verification
We used the microstepping functionality of our motor drivers to achieve better translational resolution.


- Took a full raster scan and commanded both motors return to their origin positions
- Used firmware and current tuning to end in a state where error was too small to physically measure (< 0.1 mm)
- Measured alignment error of stitched image to be < 5px

## Scanning System - Verification

Microstepping Resolution

Resolution = Pitch / 3,200 steps/rev

Full Step: 1.8° (200 steps/rev) Microsteps: 1/16 (3,200 steps/rev)

Achieves sub-millimeter precision for alignment.

## Post-Processing Pipeline

Routing Logic; Server Structure

## Post-Processing Pipeline: Negative


A simplified pipeline that follows industry standard professional software Negative Lab Pro

## Post-Processing Pipeline: Positive+Instant


## Coordination and Digital

## Subsystem Integration

## Representation

Tying all our subsystems together and coordinating hardware through software was one of the greatest challenges we faced.

State Tracking & Robustness

Our system has many failure points:

- Stuck motors
- Power outage – battery discharges
- UART disconnect
- Network errors

By defining integration points and clear “owners” for each piece of logic, we could effectively debug and develop in parallel.

# Demo


445video.mp4 (http://drive.google.com/file/d/1dBadZlyNeP5EZ2515Spu1K9EdyptU5JA/view)

## Failures and Challenges

- Soldering and verifying functionality on PCB
- PCB layout and component selection
- Time management for development and part orders

## Successes

- Testing changes in isolation
- Defining integration points before working on implementation
- Making tradeoffs and implementation decisions to support bottom line

## Reflection

# repo rt_pr oble chec m k_cir cle

## Project Conclusions

# Revisiting Design

Although we were able to build a functional prototype, we identified key areas for improvement to make the device more robust and convenient to use.

Simplifying Circuit Design

Separate logic circuits instead of having a single large one with varying physical requirements

Component Selection

Use well-documented parts with practical footprints.

Calibration Hardware

Add motor limit switches for fully automatic calibration.

Time Management

Invest more time in early design and requirements.

Safety and Battery Management

- Immediate kill switch and insulated wires
- Battery management system (regulator/fuse)
- Sealed enclosure for mechanical pinch points

Standards & Compliance

- Wi-Fi networking compliance
- JPEG standards for data transfer

## Ethical Concerns

Misuse Statement

- Warnings against scanning of illegal materials, scanning without permission, or attempting to circumvent copyright rules

Library Attributions

This project leverages several libraries for computer vision, camera control, and more
- OpenCV
- Libcamera
- FastAPI
- ReactJS

# Portability, UX, and Speed

Physical Design & Portability

Refine for a smaller footprint and utilize lighter, more durable materials.

Automated Calibration

Incorporate dedicated sensors to streamline and automate the calibration process.

Integrated UI / UX

Add a touchscreen interface to remove the dependency on external phones or laptops.

Software & Speed Optimization

Optimize software algorithms to significantly reduce overall processing time.

Advanced Vision Processing

Leverage specialized hardware accelerators or GPUs for high-speed vision processing tasks.

## Future Work


# Questions

## Thanks for listening!

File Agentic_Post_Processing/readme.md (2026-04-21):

# Agentic Post-Processing Pipeline

AI-driven film scan restoration pipeline for the ECE 445 portable film digitizer. Automatically classifies film type, applies a multi-stage OpenCV pipeline, and uses Gemini (or a heuristic fallback) to iteratively refine processing parameters until the output meets a quality threshold.

---

## Quick Start

### 1. Set up API key (optional — heuristic fallback works without it)

Create `Agentic_Post_Processing/.env`:

```
GEMINI_API_KEY=your_key_here
```

### 2. Process a directory of images

```bash
cd Agentic_Post_Processing
python orchestrator.py --input-dir data --output-dir output --max-iter 3
```

Each image produces two output files in `--output-dir`:
- `<stem>_processed.png` — the restored image
- `<stem>_meta.json` — processing metadata (film type, score, parameters, per-iteration log)

### 3. Process a single image

```bash
python _run_single.py path/to/capture.jpg path/to/output_dir/
```

Prints a JSON result to stdout and streams `PROGRESS:{json}` lines to stderr after each iteration (used by the web server for live progress display).

### 4. Run tests

```bash
python -m pytest tests -v
```

---

## Web UI Integration

The web frontend at `http://localhost:8000` has an **AI Processing** button on the Camera tab. After capturing an image:

1. Click **Process with AI** — the image is sent to the PC and the pipeline starts.
2. A live **AI Pipeline** panel appears showing:
   - Film type + agent modes (Gemini or heuristic)
   - Iteration progress bar
   - Score bar (green ≥ 70%, amber ≥ 45%, red below)
   - Per-iteration log with score, pass/fail verdict, and feedback
   - Current parameter values (expandable)
3. On completion, a **before/after comparison** is shown with final metrics.

To run the web server:

```bash
cd software
uvicorn server:app --reload --host 0.0.0.0 --port 8000
```

---

## Architecture

```
orchestrator.py
  └── process_image()
        ├── ClassifierAgent   → film type (negative_35mm | positive_35mm | medium_format)
        ├── PostProcessingAgent → OpenCV pipeline (negative.py or positive.py)
        └── EvaluatorAgent    → quality score + suggested params
              └── loop up to MAX_EVAL_ITERATIONS times
```

| File | Role |
|---|---|
| `orchestrator.py` | Entry point; classify → process → evaluate → refine loop |
| `agents/classifier.py` | Gemini vision or heuristic film type classification |
| `agents/processor.py` | Routes to the correct pipeline based on film type |
| `agents/evaluator.py` | Scores output 0–1; emits suggested parameters for next iteration |
| `pipelines/negative.py` | 13-stage negative restoration pipeline |
| `pipelines/positive.py` | 7-stage positive/slide pipeline |
| `models.py` | Shared dataclasses (`PipelineParams`, `QualityResult`) |
| `config.py` | Loads `.env`; exposes `GEMINI_API_KEY`, `MAX_EVAL_ITERATIONS`, `QUALITY_THRESHOLD` |
| `_run_single.py` | Subprocess wrapper used by the web server |

---

## Pipeline Stages

### Negative Film (`pipelines/negative.py`)

1. **Film base estimation** — samples brightest pixels and image borders to estimate the orange mask
2. **Optical-density inversion** — converts to density space, subtracts the base, inverts back
3. **Gray-world white balance** — per-channel gain normalisation (clamped to [0.5, 1.8])
4. **Highlight compression** — soft-clips blown highlights before further processing
5. **Gamma correction** — `output = input ^ gamma` (gamma < 1 brightens, gamma > 1 darkens)
6. **Shadow lift** — additive floor lift for crushed shadows
7. **LAB cast neutralisation** — suppresses residual colour cast in LAB a/b channels
8. **CLAHE** — contrast-limited adaptive histogram equalisation on the L channel
9. **Vibrance boost** — weighted saturation increase (low-saturation pixels boosted most)
10. **Final gray-world pass** — tightens residual per-channel imbalance (clamped to [0.75, 1.35])
11. **Second LAB neutralisation** — removes any cast reintroduced by CLAHE
12. **Selective desaturation** — suppresses specific colour cast hues via HSV-space mask
13. **Unsharp mask** — recovers fine grain and edge detail

### Positive / Slide Film (`pipelines/positive.py`)

1. White balance (percentile stretch per channel)
2. Shadow lift
3. Gamma correction
4. Highlight compression
5. CLAHE
6. Vibrance boost
7. Unsharp mask

---

## Pipeline Parameters

All 14 parameters are tuned automatically by the evaluator. Ranges and defaults:

| Parameter | Range | Default | Effect |
|---|---|---|---|
| `wb_clip_percent` | 0.2 – 1.5 | 0.5 | Percentile used for white-balance stretch; higher clips more |
| `black_point` | 0.5 – 2.0 | 0.8 | Black-point percentile for tone mapping |
| `white_point` | 97.0 – 99.5 | 99.2 | White-point percentile for tone mapping |
| `clahe_clip` | 0.5 – 4.0 | 1.4 | CLAHE clip limit; higher = more contrast |
| `clahe_grid` | 4, 8, or 16 | 8 | CLAHE tile grid size; smaller = more localised |
| `unsharp_amount` | 0.0 – 1.0 | 0.35 | Unsharp mask strength |
| `unsharp_sigma` | 0.5 – 3.0 | 1.2 | Gaussian blur radius for unsharp mask |
| `desat_strength` | 0.0 – 0.6 | 0.20 | Selective desaturation mask strength |
| `desat_sigma` | 2.0 – 20.0 | 7.0 | Hue width for selective desaturation |
| `shadow_lift` | 0.0 – 40.0 | 0.0 | Additive lift applied to all pixels before CLAHE |
| `gamma` | 0.4 – 2.2 | 1.0 | Power-law gamma: < 1 brightens, > 1 darkens, 1 = no-op |
| `lab_strength` | 0.0 – 1.5 | 0.85 | LAB cast neutralisation strength; > 1 is aggressive |
| `highlight_compression` | 0.0 – 0.5 | 0.0 | Soft highlight rolloff; use 0.2–0.4 if white is clipping |
| `vibrance` | −0.3 – 0.6 | 0.0 | Weighted saturation boost; affects unsaturated pixels most |

---

## Evaluator Metrics

Written to `<stem>_meta.json` under `evaluation_metrics`:

| Metric | Ideal range | What it measures |
|---|---|---|
| `gray_mean` | 100 – 165 | Overall exposure (0 = black, 255 = white) |
| `gray_std` | — | Tonal contrast |
| `clipped_black_ratio` | < 0.005 | Fraction of pixels crushed to near-black (≤ 2) |
| `clipped_white_ratio` | < 0.005 | Fraction of pixels blown to near-white (≥ 253) |
| `blue_red_delta` | ≈ 0 | Blue–red channel imbalance (positive = blue/cyan cast) |
| `green_magenta_delta` | ≈ 0 | Green–magenta channel imbalance |
| `channel_spread` | < 0.10 | Max − min of channel means (lower = more balanced) |
| `mean_saturation` | 0.08 – 0.45 | Average HSV saturation (< 0.04 may indicate demasking failure) |
| `laplacian_variance` | > 150 | Sharpness proxy (< 80 = soft) |

---

## Configuration

Edit `config.py` or set environment variables in `.env`:

| Variable | Default | Description |
|---|---|---|
| `GEMINI_API_KEY` | *(none)* | Existing stable Gemini key for the main fast path |
| `VLM_MODEL` | `gemini-2.5-flash` | Main classifier/evaluator model |
| `MAX_EVAL_ITERATIONS` | `3` | Maximum refinement iterations per image |
| `QUALITY_THRESHOLD` | `0.75` | Score ≥ this value → pipeline exits early (quality passed) |
| `DECISION_MODEL_ENABLED` | `0` | Enable optional high-level escalation model |
| `OPENAI_API_KEY` | *(none)* | Gateway key for escalation-only high-level decisions |
| `OPENAI_BASE_URL` | *(none)* | OpenAI-compatible gateway base URL |
| `DECISION_MODEL` | `gpt-5-mini` | Primary high-level strategy model, chosen for measured stability |
| `DECISION_MODEL_FALLBACK` | `gpt-5.1-chat` | Stronger but currently less stable fallback tier |
| `DECISION_MODEL_EXPERT` | `gpt-5-pro` | Expert tier reserved for the hardest cases |
| `DECISION_SCORE_TRIGGER` | `0.55` | Escalate when score is at or below this threshold |
| `DECISION_MIN_ITERATION` | `2` | Earliest iteration allowed to call the decision model |

### Decision-model escalation path

The stable Gemini-based agentic pipeline remains the default fast path.
An optional escalation-only strategy model can be enabled for difficult cases.
When enabled, the orchestrator may call a stronger gateway-backed model such as
`gpt-5.2` only when:
- the current iteration is at least `DECISION_MIN_ITERATION`
- the evaluator score is at or below `DECISION_SCORE_TRIGGER`
- the normal fast path has not already passed the quality threshold

This preserves Gemini as the main and rollback path while allowing stronger
high-level parameter decisions on hard examples.

Recommended escalation tiering:
- primary decision tier: `gpt-5-mini`
- secondary tier: `gpt-5.1-chat`
- expert tier: `gpt-5-pro`

---

## Output Metadata Example

```json
{
  "source": "capture_20240101_120000.jpg",
  "film_type": "negative_35mm",
  "classifier_mode": "gemini",
  "evaluator_mode": "gemini",
  "iterations": 2,
  "selected_iteration": 2,
  "final_score": 0.821,
  "passed": true,
  "feedback": "Good exposure, colour balance, and detail.",
  "final_params": {
    "gamma": 0.85,
    "lab_strength": 1.1,
    "clahe_clip": 1.6,
    ...
  },
  "evaluation_metrics": {
    "gray_mean": 134.7,
    "clipped_white_ratio": 0.002,
    "mean_saturation": 0.18,
    "laplacian_variance": 210.4,
    ...
  }
}
```

---

## Experimental: `raw_pipeline` package (work-in-progress)

`raw_pipeline/` is a new, additive package implementing a physically-grounded
RAW-aware negative inversion pipeline as described in `pipeline_update.md`.
It does **not** modify or replace the existing agentic pipeline.

### Design

The package separates two concerns that the current pipeline merges:

| Stage | Modules |
|---|---|
| **Technical inversion** | `raw_ingest`, `sensor_normalization`, `flat_field`, `border_detection`, `film_characterization`, `density_inversion` |
| **Aesthetic rendering** | `rendering` |
| **Stage-aware diagnostics** | `diagnostics` |

### Quick start

```bash
cd Agentic_Post_Processing
python - <<'EOF'
from raw_pipeline import process_raw_negative
result = process_raw_negative(
    frame_raw_path="path/to/frame.dng",
    flat_raw_path="path/to/flat.dng",
    output_dir="/tmp/raw_out",
)
print(result["evaluator_output"]["overall_score"])
EOF
```

JPEG/PNG inputs are accepted as a fallback for testing without actual RAW files.
A `rawpy` install is required for true RAW (DNG/ARW/RAF) input:
```bash
pip install rawpy
```

### Status

Phase 1–5 (ingest → flat-field → border detection → characterisation →
inversion → rendering → diagnostics) are implemented as first-pass working
code.  Leader-based calibration (`border_plus_leader` mode) is supported but
not yet validated on real IMX477 captures.  Results should be treated as
experimental until tested against real RAW scans.

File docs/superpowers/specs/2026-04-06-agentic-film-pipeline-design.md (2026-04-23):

# Agentic Film Post-Processing Pipeline — Design Spec

**Date:** 2026-04-06  
**Status:** Approved  
**Location:** `Agentic_Post_Processing/`

---

## Overview

A sequential agentic pipeline that takes a single full-resolution film scan, classifies the film type using Gemini vision, routes it to the appropriate post-processing pipeline, and evaluates quality with an automated feedback loop.

---

## Supported Film Types

| FilmType enum | Description |
|---|---|
| `NEGATIVE_35MM` | 35mm color negative (orange base)  |
| `NEGATIVE_120` | 120 medium format color negative |
| `POSITIVE_35MM` | 35mm slide / transparency |
| `POSITIVE_120` | 120 medium format slide |

---

## File Layout

```
Agentic_Post_Processing/
├── agents/
│   ├── __init__.py
│   ├── classifier.py       # ClassifierAgent — Gemini vision, returns FilmType
│   ├── processor.py        # PostProcessingAgent — routes to pipeline, returns image
│   └── evaluator.py        # EvaluatorAgent — Gemini vision, returns QualityResult
├── pipelines/
│   ├── __init__.py
│   ├── negative.py         # Negative pipeline: invert → WB → CLAHE → desat → unsharp
│   └── positive.py         # Positive pipeline: WB → shadow lift → CLAHE → unsharp
├── orchestrator.py         # Main loop: classify → process → evaluate → loop
├── config.py               # API keys, model names, thresholds (reads from .env)
├── models.py               # Shared dataclasses: FilmType, PipelineParams, QualityResult
├── .env                    # Real secrets — gitignored
├── .env.example            # Safe template to commit
└── data/                   # Input images
```

---

## Data Flow

```
input image path
  │
  ▼
ClassifierAgent (Gemini VLM)
  → FilmType
  │
  ▼
PostProcessingAgent
  → pipelines/negative.py  OR  pipelines/positive.py
  → accepts PipelineParams dataclass
  → returns np.ndarray
  │
  ▼
EvaluatorAgent (Gemini VLM)
  → QualityResult { score, passed, feedback, suggested_params }
  │
  ├─ passed OR iter >= MAX_ITER  →  save output, done
  └─ failed                      →  PostProcessingAgent(suggested_params), iter++
```

---

## Shared Models (`models.py`)

```python
from enum import Enum
from dataclasses import dataclass, field

class FilmType(Enum):
    NEGATIVE_35MM = "negative_35mm"
    NEGATIVE_120  = "negative_120"
    POSITIVE_35MM = "positive_35mm"
    POSITIVE_120  = "positive_120"

@dataclass
class PipelineParams:
    # Shared
    wb_clip_percent: float = 0.5
    black_point:     float = 0.8
    white_point:     float = 99.2
    clahe_clip:      float = 1.4
    unsharp_amount:  float = 0.35
    # Negative only
    desat_strength:  float = 0.20
    desat_sigma:     float = 7.0
    # Positive only
    shadow_lift:     float = 0.0   # additive lift, 0–30 typical

@dataclass
class QualityResult:
    score:             float          # 0.0–1.0
    passed:            bool
    feedback:          str
    suggested_params:  PipelineParams
```

---

## Agent Designs

### ClassifierAgent (`agents/classifier.py`)

- Encodes input image as base64, sends to Gemini VLM (`VLM_MODEL`)
- Prompt encodes classification rules:
  - Dark/black border → positive film
  - Orange overall tint + inverted luminance → negative film
  - Aspect ratio heuristic for 35mm vs 120 (35mm ≈ 3:2, 120 ≈ 1:1 or 6:7)
  - Gemini resolves ambiguous cases
- Returns `FilmType`
- Configurable model via `config.VLM_MODEL` — swap string to compare `gemini-2.5-flash` vs `gemini-2.5-pro`

### PostProcessingAgent (`agents/processor.py`)

- Pure OpenCV — no LLM
- Dispatches to `pipelines/negative.py` or `pipelines/positive.py` by `FilmType`
- Both 35mm and 120 use the same pipeline logic (format affects classification, not processing)
- Accepts `PipelineParams`, returns `np.ndarray`

### EvaluatorAgent (`agents/evaluator.py`)

- Encodes processed image as base64, sends to Gemini VLM
- Prompt asks model to score on: exposure (clipping), color balance, sharpness, artifacts
- Parses JSON response: `{ score, feedback, suggested_params }`
- Returns `QualityResult`
- If score >= `config.QUALITY_THRESHOLD` (default 0.75): `passed=True`
- `suggested_params` always populated — used only if `passed=False`

---

## Pipelines

### `pipelines/negative.py`

Stages (adapted from existing `negative_pipeline.py`, single-image interface):
1. Invert: `255 - image`
2. White balance (percentile-clipped)
3. Per-channel level stretch
4. Luminance CLAHE
5. Selective desaturation mask + application
6. Unsharp mask

### `pipelines/positive.py`

Stages:
1. White balance (percentile-clipped)
2. Shadow lift: `np.clip(image.astype(float) + shadow_lift, 0, 255)`
3. Luminance CLAHE (lower clip limit, ~1.0)
4. Unsharp mask

Both pipelines accept `PipelineParams` and return `np.ndarray`.

---

## Orchestrator (`orchestrator.py`)

```
for each image in data/:
    film_type = ClassifierAgent.classify(image_path)
    params = PipelineParams()   # defaults
    for i in range(MAX_EVAL_ITERATIONS):
        result_img = PostProcessingAgent.process(image, film_type, params)
        quality = EvaluatorAgent.evaluate(result_img)
        if quality.passed:
            break
        params = quality.suggested_params
    save result_img to output/<stem>_processed.png
    save metadata JSON: film_type, iterations, final_score, feedback
```

---

## Config (`config.py`)

Reads from `.env` via `python-dotenv`:

```python
GEMINI_API_KEY       = _env_first("GEMINI_API_KEY", "GOOGLE_API_KEY", default="")
VLM_MODEL            = _env_first("VLM_MODEL", "GEMINI_VLM_MODEL", default="gemini-2.5-flash")
LLM_MODEL            = _env_first("LLM_MODEL", "GEMINI_LLM_MODEL", default="gemini-2.5-flash")
MAX_EVAL_ITERATIONS  = 3
QUALITY_THRESHOLD    = 0.75
```

---

## Error Handling

- If Gemini returns unparseable JSON from evaluator: retain current params, log warning, count as iteration used
- If Gemini classification is ambiguous: default to `NEGATIVE_35MM`, log warning
- If pipeline raises exception: propagate with image path in message

---
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

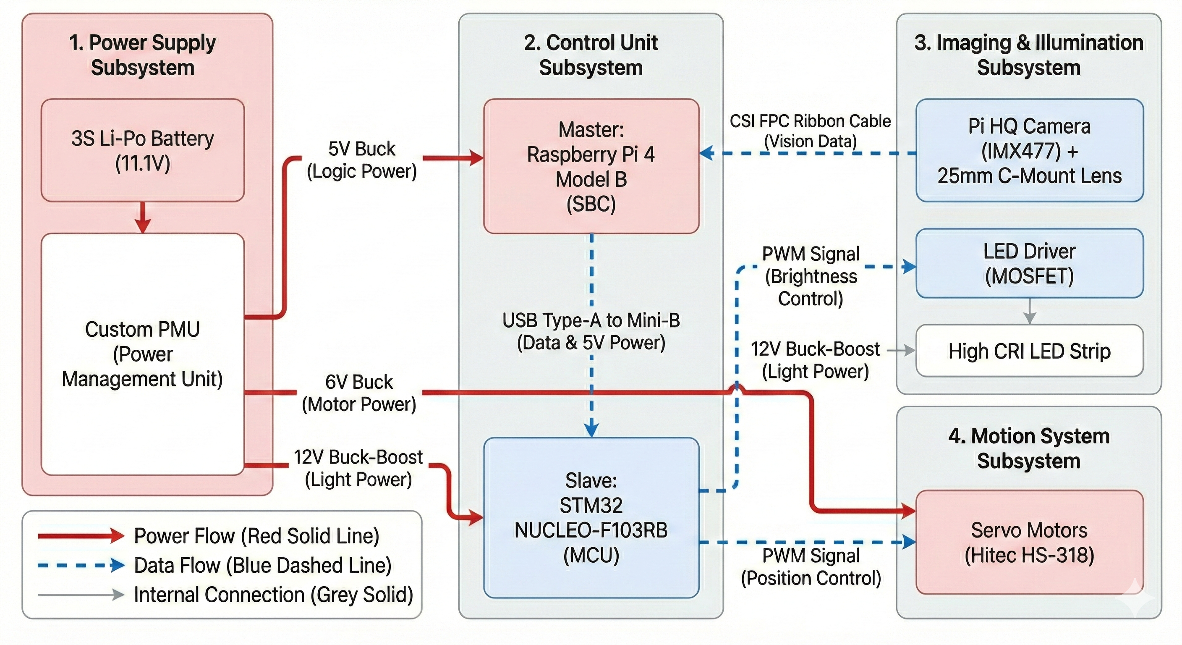
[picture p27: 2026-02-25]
Block_Diagram.png

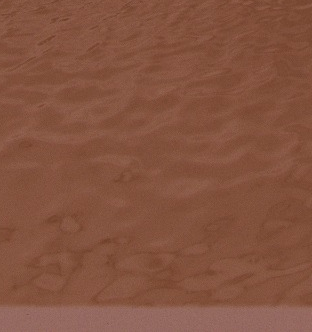
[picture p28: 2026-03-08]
Image_integration&Post_Processing/Negative_example/norway_split_40_overlap/tile_r05_c04_36.png

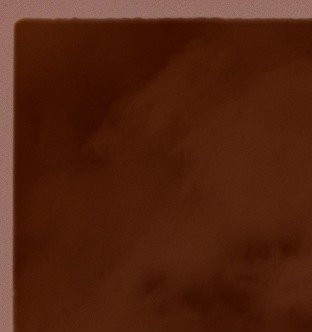
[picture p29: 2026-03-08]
Image_integration&Post_Processing/Negative_example/norway_split_40_overlap/tile_r01_c01_01.png

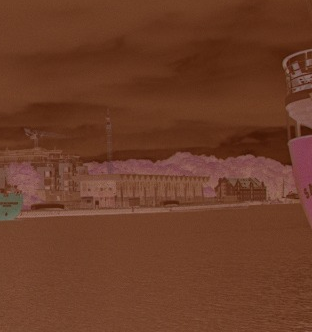
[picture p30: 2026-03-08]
Image_integration&Post_Processing/Negative_example/norway_split_40_overlap/tile_r03_c06_22.png

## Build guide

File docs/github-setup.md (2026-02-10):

# GitHub Setup

This guide takes the local project in this folder and publishes it to GitHub.

## 1. Initialize Git Locally (Already Done in This Workspace)
```powershell
git init -b main
git add .
git commit -m "Initial project scaffold"
```

## 2. Authenticate GitHub CLI
In this environment, `gh` is installed at `C:\Program Files\GitHub CLI\gh.exe`.

Authenticate once:
```powershell
& "C:\Program Files\GitHub CLI\gh.exe" auth login
```

## 3. One-Command Publish + Invite
Run the bootstrap script from repo root:
```powershell
.\scripts\github-bootstrap.ps1 -GitHubUsername <your-github-username> -RepoName ece-445-film-digitizer -Visibility private -Collaborator Allannn-sudo
```

This will:
- create the GitHub repository,
- push the local `main` branch,
- invite `Allannn-sudo` as collaborator with push access.

## 4. Manual Commands (Alternative)
```powershell
& "C:\Program Files\GitHub CLI\gh.exe" repo create ece-445-film-digitizer --private --source . --remote origin --push
& "C:\Program Files\GitHub CLI\gh.exe" api -X PUT repos/<your-github-username>/ece-445-film-digitizer/collaborators/Allannn-sudo -f permission=push
```

## 5. Web UI Fallback (No CLI)
1. Create a new private repo on GitHub.
2. In this folder run:
```powershell
git remote add origin https://github.com/<your-github-username>/<repo-name>.git
git branch -M main
git push -u origin main
```
3. Open GitHub repo settings: `Settings` -> `Collaborators and teams`.
4. Click `Add people`, enter `Allannn-sudo`, and send invite.

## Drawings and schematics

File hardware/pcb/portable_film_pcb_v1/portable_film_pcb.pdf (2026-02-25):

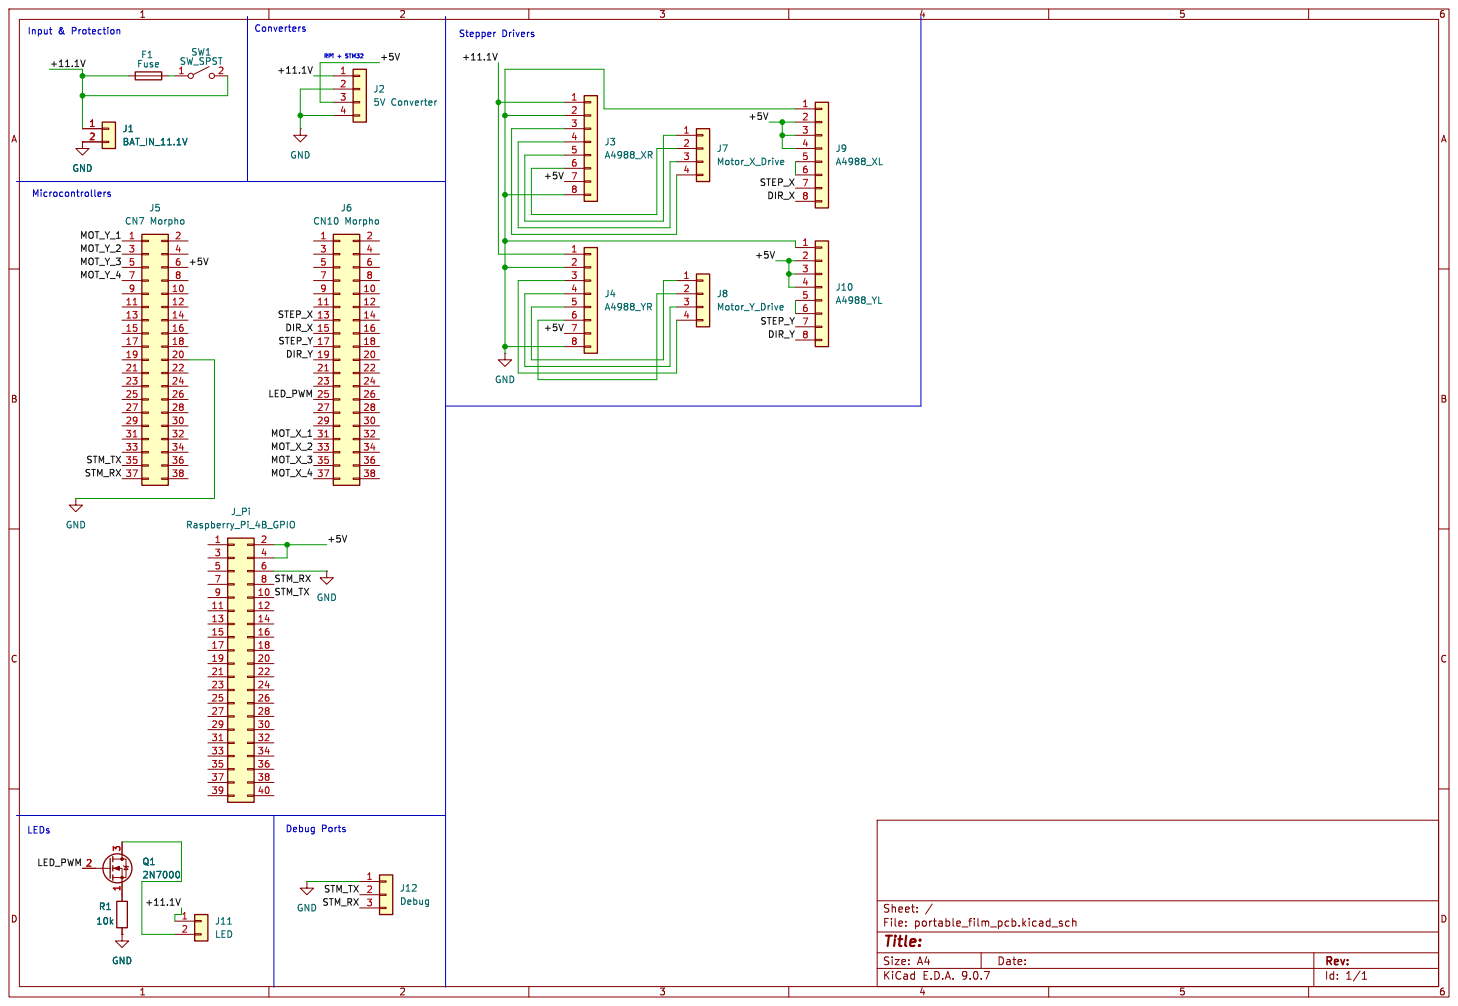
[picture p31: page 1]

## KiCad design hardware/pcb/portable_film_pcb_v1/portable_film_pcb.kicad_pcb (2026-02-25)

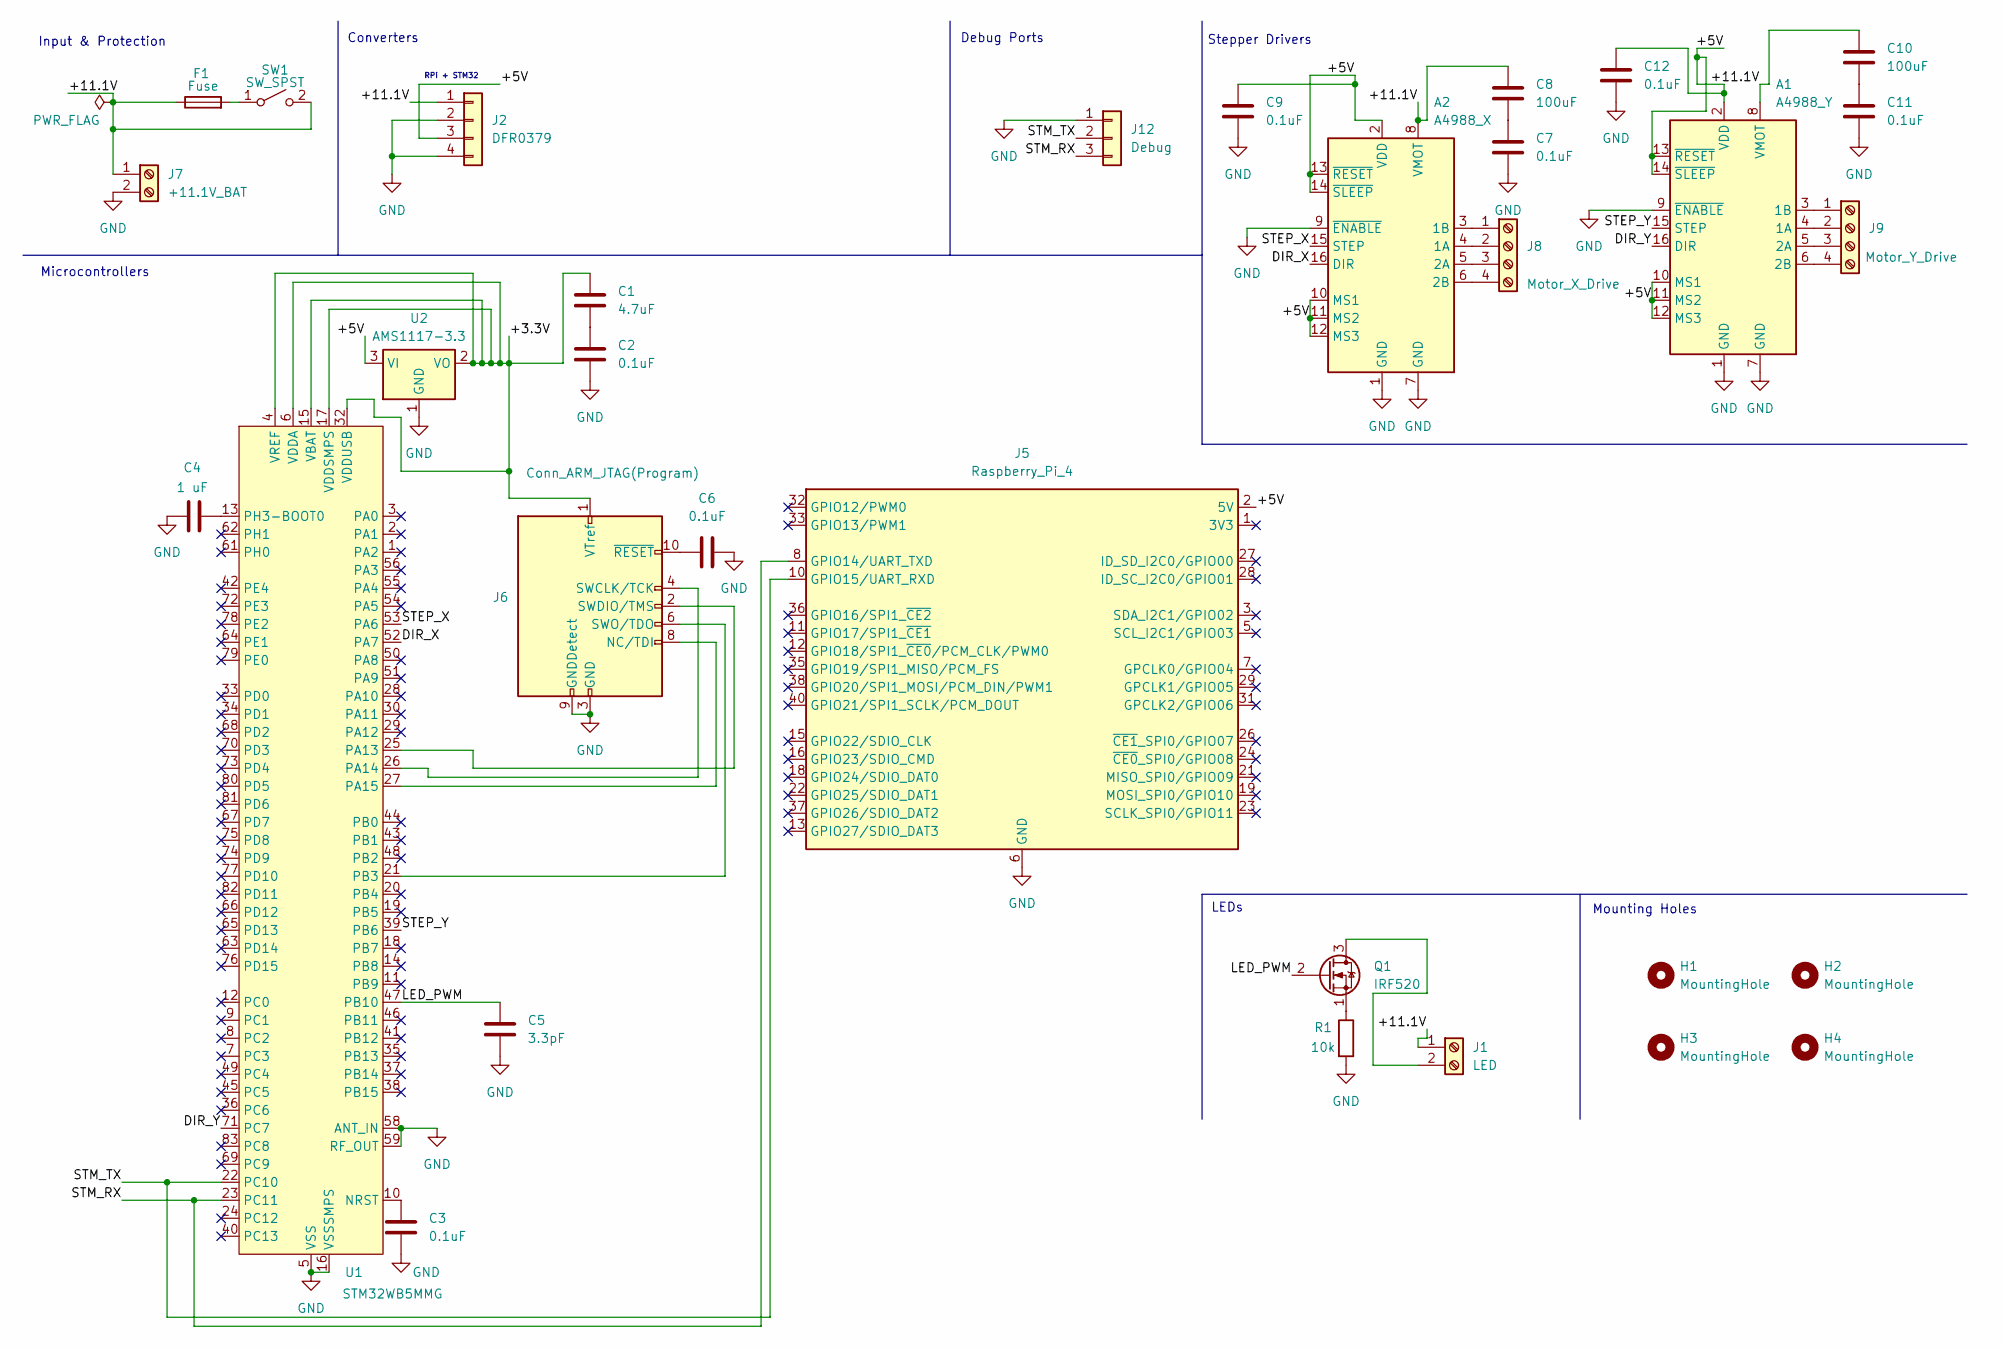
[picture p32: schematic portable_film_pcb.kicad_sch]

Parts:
A1: A4988_Y; Pololu_Breakout-16_15.2x20.3mm
A2: A4988_X; Pololu_Breakout-16_15.2x20.3mm
C1: 4.7uF; CP_Radial_D5.0mm_P2.00mm
C2, C3, C6, C7, C9, C11, C12: 0.1uF; C_Disc_D5.0mm_W2.5mm_P2.50mm
C4: 1 uF; C_Disc_D5.0mm_W2.5mm_P5.00mm
C5: 3.3pF; C_0201_0603Metric
C8, C10: 100uF; CP_Radial_D8.0mm_P3.50mm
F1: Fuse; FuseHolder_Blade_ATO_Littelfuse_FLR_178.6165
H1, H2, H3, H4: MountingHole; MountingHole_3.2mm_M3
J1: LED; TerminalBlock_Phoenix_PT-1,5-2-3.5-H_1x02_P3.50mm_Horizontal
J2: DFR0379; TerminalBlock_Phoenix_MKDS-1,5-4-5.08_1x04_P5.08mm_Horizont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
J5: Raspberry_Pi_4; PinSocket_2x20_P2.54mm_Vertical
J6: Conn_ARM_JTAG(Program); PinHeader_2x05_P1.27mm_Vertical
J7: +11.1V_BAT; TerminalBlock_Phoenix_PT-1,5-2-3.5-H_1x02_P3.50mm_Horizontal
J8: Motor_X_Drive; TerminalBlock_Phoenix_MPT-0,5-4-2.54_1x04_P2.54mm_Horizontal
J9: Motor_Y_Drive; TerminalBlock_Phoenix_MPT-0,5-4-2.54_1x04_P2.54mm_Horizontal
J12: Debug; PinSocket_1x03_P2.54mm_Vertical
Q1: IRF520; TO-92_Inline
R1: 10k; R_Axial_DIN0207_L6.3mm_D2.5mm_P7.62mm_Horizontal
SW1: SW_SPST; TerminalBlock_Phoenix_MKDS-1,5-2-5.08_1x02_P5.08mm_Horizont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
U1: STM32WB5MMG; ST-SiP-LGA-86-11x7.3mm
U2: AMS1117-3.3; SOT-223-3_TabPin2

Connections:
/+3.3V: C1.1, J6.1 (VTref), U1.4 (VREF), U1.6 (VDDA), U1.15 (VBAT), U1.17 (VDDSMPS), U1.32 (VDDUSB), U2.2 (VO)
/+5V: A1.2 (VDD), A1.10 (MS1), A1.11 (MS2), A1.12 (MS3), A1.13 (~RESET), A1.14 (~SLEEP), A2.2 (VDD), A2.10 (MS1), A2.11 (MS2), A2.12 (MS3), A2.13 (~RESET), A2.14 (~SLEEP), C9.1, C12.1, J2.3, J5.2 (5V), J5.4 (5V), U2.3 (VI)
/+11.1V: A1.8 (VMOT), A2.8 (VMOT), C8.1, C10.1, F1.1, J1.1, J2.1, J7.1, SW1.2 (B)
/DIR_X: A2.16 (DIR), U1.52 (PA7)
/DIR_Y: A1.16 (DIR), U1.71 (PC7)
/LED_PWM: C5.1, Q1.2 (G), U1.47 (PB10)
/STEP_X: A2.15 (STEP), U1.53 (PA6)
/STEP_Y: A1.15 (STEP), U1.39 (PB6)
/STM_RX: J5.8 (GPIO14/UART_TXD), J12.3, U1.23 (PC11)
/STM_TX: J5.10 (GPIO15/UART_RXD), J12.2, U1.22 (PC10)
GND: A1.1 (GND), A1.7 (GND), A1.9 (~ENABLE), A2.1 (GND), A2.7 (GND), A2.9 (~ENABLE), C2.2, C3.2, C4.1, C5.2, C6.2, C7.2, C9.2, C11.2, C12.2, J2.2, J2.4, J5.6 (GND), J5.9 (GND), J5.14 (GND), J5.20 (GND), J5.25 (GND), J5.30 (GND), J5.34 (GND), J5.39 (GND), J6.3 (GND), J6.5 (GND), J6.9 (GNDDetect), J7.2, J12.1, R1.2, U1.5 (VSS), U1.16 (VSSSMPS), U1.31 (VSS), U1.57 (VSS), U1.58 (ANT_IN), U1.59 (RF_OUT), U1.60 (VSS), U1.84 (VSS), U1.86 (VSS), U2.1 (GND)
unnamed: A1.4 (1A), J9.2
unnamed: A1.3 (1B), J9.1
unnamed: A1.5 (2A), J9.3
unnamed: A1.6 (2B), J9.4
unnamed: A2.4 (1A), J8.2
unnamed: A2.3 (1B), J8.1
unnamed: A2.5 (2A), J8.3
unnamed: A2.6 (2B), J8.4
unnamed: C1.2, C2.1
unnamed: C7.1, C8.2
unnamed: C10.2, C11.1
unnamed: J1.2, Q1.3 (D)
unnamed: J6.8 (NC/TDI), U1.27 (PA15)
unnamed: J6.4 (SWCLK/TCK), U1.26 (PA14)
unnamed: J6.2 (SWDIO/TMS), U1.25 (PA13)
unnamed: J6.6 (SWO/TDO), U1.21 (PB3)
unnamed: C6.1, J6.10 (~RESET)
unnamed: Q1.1 (S), R1.1
unnamed: F1.2, SW1.1 (A)
unnamed: C3.1, U1.10 (NRST)
unnamed: C4.2, U1.13 (PH3-BOOT0)

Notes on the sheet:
LEDs
Converters
Stepper Drivers
Microcontrollers
Mounting Holes
Input & Protection
Debug Ports
RPi + STM32

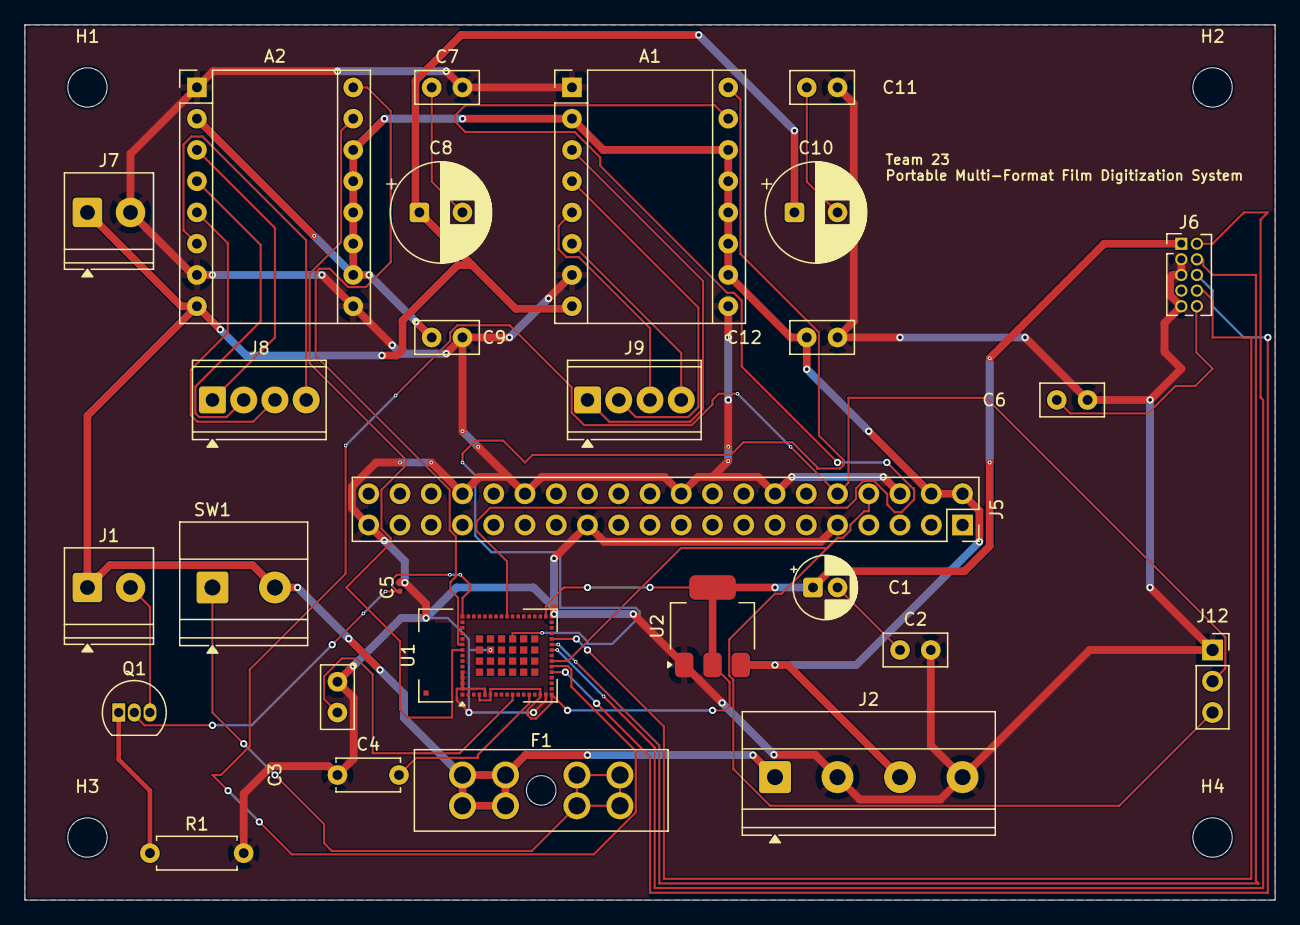
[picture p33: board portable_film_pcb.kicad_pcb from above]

Board: 2 copper layers, 101.6 x 71.1 mm, 32 parts (0 on the bottom side), 32 nets.

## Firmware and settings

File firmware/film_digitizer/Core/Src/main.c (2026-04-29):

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

/* Includes ------------------------------------------------------------------*/
#include "main.h"
#include "usart.h"
#include "gpio.h"
#include <stdio.h>
#include <stdlib.h>
#include <string.h>

void SystemClock_Config(void);
void DWT_Init(void);
void delay_us(uint32_t us);
void Process_Command(char* buffer, UART_HandleTypeDef *huart);
void Step_Motor(GPIO_TypeDef* port, uint16_t pin, uint32_t delay);

/* USER CODE BEGIN PV */
uint8_t rx1_byte;
char rx1_buffer[64];
uint8_t rx1_index = 0;

char active_cmd[64];
volatile uint8_t cmd_ready = 0;
volatile uint8_t stop_flag = 0;
UART_HandleTypeDef *active_huart = NULL;

typedef enum {
    MOTOR_IDLE,
    MOTOR_JOG_X_FWD,
    MOTOR_JOG_X_REV,
    MOTOR_JOG_Y_FWD,
    MOTOR_JOG_Y_REV,
    MOTOR_BUSY_API
} MotorState_t;

volatile MotorState_t motor_state = MOTOR_IDLE;

const uint32_t RAMP_START_DELAY = 800;
const uint32_t RAMP_MIN_DELAY = 100;
/* USER CODE END PV */

int main(void)
{
  HAL_Init();
  SystemClock_Config();
  MX_GPIO_Init();
  MX_USART1_UART_Init();

  /* USER CODE BEGIN 2 */
  DWT_Init();
  HAL_UART_Receive_IT(&huart1, &rx1_byte, 1);

  uint32_t current_jog_delay = RAMP_START_DELAY;
  uint32_t ramp_counter = 0;
  uint32_t last_heartbeat = 0;

  char boot_msg[] = "\r\n--- Dual Axis Interface (X & Y) ---\r\n"
                    "A/D: Jog X | W/S: Jog Y | Q: Stop\r\n"
                    "API: $MX:steps; or $MY:steps;\r\n";
  HAL_UART_Transmit(&huart1, (uint8_t*)boot_msg, strlen(boot_msg), 100);
  /* USER CODE END 2 */

  while (1)
  {
    // Status LED logic
    if (motor_state != MOTOR_IDLE) {
        HAL_GPIO_WritePin(LD2_GPIO_Port, LD2_Pin, GPIO_PIN_SET);
    } else {
        if (HAL_GetTick() - last_heartbeat > 500) {
            HAL_GPIO_TogglePin(LD2_GPIO_Port, LD2_Pin);
            last_heartbeat = HAL_GetTick();
        }
    }

    // 1. Handle Precise API Movements ($MX:1000; or $MY:1000;)
    if (cmd_ready && active_huart != NULL)
    {
      motor_state = MOTOR_BUSY_API;
      Process_Command(active_cmd, active_huart);
      motor_state = MOTOR_IDLE;
      cmd_ready = 0;
    }

    // 2. Dual Axis Jogging Logic
    if (motor_state != MOTOR_IDLE && motor_state != MOTOR_BUSY_API)
    {
      GPIO_TypeDef* step_port;
      uint16_t step_pin;

      // Determine Direction and Pins based on state
      if (motor_state == MOTOR_JOG_X_FWD || motor_state == MOTOR_JOG_X_REV) {
          HAL_GPIO_WritePin(DIR_X_PIN_GPIO_Port, DIR_X_PIN_Pin, (motor_state == MOTOR_JOG_X_FWD) ? GPIO_PIN_RESET : GPIO_PIN_SET);
          step_port = STEP_X_PIN_GPIO_Port;
          step_pin = STEP_X_PIN_Pin;
      } else {
          HAL_GPIO_WritePin(DIR_Y_PIN_GPIO_Port, DIR_Y_PIN_Pin, (motor_state == MOTOR_JOG_Y_FWD) ? GPIO_PIN_RESET : GPIO_PIN_SET);
          step_port = STEP_Y_PIN_GPIO_Port;
          step_pin = STEP_Y_PIN_Pin;
      }

      // Execute Step
      HAL_GPIO_WritePin(step_port, step_pin, GPIO_PIN_SET);
      delay_us(current_jog_delay);
      HAL_GPIO_WritePin(step_port, step_pin, GPIO_PIN_RESET);
      delay_us(current_jog_delay);

      // Simple Ramp
      if (current_jog_delay > RAMP_MIN_DELAY) {
          ramp_counter++;
          if (ramp_counter >= 2) {
              current_jog_delay--;
              ramp_counter = 0;
          }
      }
    }
    else
    {
      current_jog_delay = RAMP_START_DELAY;
      ramp_counter = 0;
    }
  }
}

/**
  * @brief UART Rx Callback
  */
void HAL_UART_RxCpltCallback(UART_HandleTypeDef *huart)
{
  if (huart->Instance == USART1) {
    if (rx1_byte == 'q' || rx1_byte == 'Q') {
      stop_flag = 1;
      motor_state = MOTOR_IDLE;
    }
    // X-Axis Jog (A/D)
    else if (rx1_byte == 'd') { motor_state = MOTOR_JOG_X_FWD; stop_flag = 0; }
    else if (rx1_byte == 'a') { motor_state = MOTOR_JOG_X_REV; stop_flag = 0; }
    // Y-Axis Jog (W/S)
    else if (rx1_byte == 'w') { motor_state = MOTOR_JOG_Y_FWD; stop_flag = 0; }
    else if (rx1_byte == 's') { motor_state = MOTOR_JOG_Y_REV; stop_flag = 0; }
    else {
      if (rx1_byte == ';') {
        rx1_buffer[rx1_index] = '\0';
        strcpy(active_cmd, rx1_buffer);
        active_huart = huart;
        cmd_ready = 1;
        rx1_index = 0;
      }
      else if (rx1_byte == '$') { rx1_index = 0; }
      else if (rx1_index < 63) { rx1_buffer[rx1_index++] = rx1_byte; }
    }

    HAL_UART_Transmit(huart, &rx1_byte, 1, 10);
    HAL_UART_Receive_IT(huart, &rx1_byte, 1);
  }
}

/**
  * @brief API Movement Processing for X and Y
  */
void Process_Command(char* buffer, UART_HandleTypeDef *huart)
{
  GPIO_TypeDef* step_port;
  uint16_t step_pin;
  GPIO_TypeDef* dir_port;
  uint16_t dir_pin;

  // Identify Axis
  if (strncmp(buffer, "MX:", 3) == 0) {
      step_port = STEP_X_PIN_GPIO_Port; step_pin = STEP_X_PIN_Pin;
      dir_port = DIR_X_PIN_GPIO_Port;   dir_pin = DIR_X_PIN_Pin;
  } else if (strncmp(buffer, "MY:", 3) == 0) {
      step_port = STEP_Y_PIN_GPIO_Port; step_pin = STEP_Y_PIN_Pin;
      dir_port = DIR_Y_PIN_GPIO_Port;   dir_pin = DIR_Y_PIN_Pin;
  } else {
      return; // Unknown command
  }

  int32_t steps = atoi(&buffer[3]);
  uint32_t speed_delay = RAMP_START_DELAY;
  stop_flag = 0;

  HAL_GPIO_WritePin(dir_port, dir_pin, (steps > 0) ? GPIO_PIN_RESET : GPIO_PIN_SET);
  steps = (steps < 0) ? -steps : steps;

  for (int32_t i = 0; i < steps; i++)
  {
    if (stop_flag) break;
    HAL_GPIO_WritePin(step_port, step_pin, GPIO_PIN_SET);
    delay_us(speed_delay);
    HAL_GPIO_WritePin(step_port, step_pin, GPIO_PIN_RESET);
    delay_us(speed_delay);
    if (speed_delay > RAMP_MIN_DELAY && i % 2 == 0) speed_delay--;
  }

  char msg[128];
  sprintf(msg, "\r\n%s: %s\r\n", stop_flag ? "STOPPED" : "OK", buffer);
  HAL_UART_Transmit(huart, (uint8_t*)msg, strlen(msg), 100);
  stop_flag = 0;
}

void DWT_Init(void) {
  CoreDebug->DEMCR |= CoreDebug_DEMCR_TRCENA_Msk;
  DWT->CYCCNT = 0;
  DWT->CTRL |= DWT_CTRL_CYCCNTENA_Msk;
}

void delay_us(uint32_t us) {
  uint32_t startTick = DWT->CYCCNT;
  uint32_t delayTicks = us * (SystemCoreClock / 1000000);
  while (DWT->CYCCNT - startTick < delayTicks);
}

void HAL_UART_ErrorCallback(UART_HandleTypeDef *huart) {
    if (huart->Instance == USART1) HAL_UART_Receive_IT(&huart1, &rx1_byte, 1);
}

void SystemClock_Config(void)
{
  RCC_OscInitTypeDef RCC_OscInitStruct = {0};
  RCC_ClkInitTypeDef RCC_ClkInitStruct = {0};
  __HAL_RCC_PWR_CLK_ENABLE();
  __HAL_PWR_VOLTAGESCALING_CONFIG(PWR_REGULATOR_VOLTAGE_SCALE2);
  RCC_OscInitStruct.OscillatorType = RCC_OSCILLATORTYPE_HSI;
  RCC_OscInitStruct.HSIState = RCC_HSI_ON;
  RCC_OscInitStruct.HSICalibrationValue = RCC_HSICALIBRATION_DEFAULT;
  RCC_OscInitStruct.PLL.PLLState = RCC_PLL_ON;
  RCC_OscInitStruct.PLL.PLLSource = RCC_PLLSOURCE_HSI;
  RCC_OscInitStruct.PLL.PLLM = 16;
  RCC_OscInitStruct.PLL.PLLN = 336;
  RCC_OscInitStruct.PLL.PLLP = RCC_PLLP_DIV4;
  RCC_OscInitStruct.PLL.PLLQ = 7;
  HAL_RCC_OscConfig(&RCC_OscInitStruct);
  RCC_ClkInitStruct.ClockType = RCC_CLOCKTYPE_HCLK|RCC_CLOCKTYPE_SYSCLK|RCC_CLOCKTYPE_PCLK1|RCC_CLOCKTYPE_PCLK2;
  RCC_ClkInitStruct.SYSCLKSource = RCC_SYSCLKSOURCE_PLLCLK;
  RCC_ClkInitStruct.AHBCLKDivider = RCC_SYSCLK_DIV1;
  RCC_ClkInitStruct.APB1CLKDivider = RCC_HCLK_DIV2;
  RCC_ClkInitStruct.APB2CLKDivider = RCC_HCLK_DIV1;
  HAL_RCC_ClockConfig(&RCC_ClkInitStruct, FLASH_LATENCY_2);
}

void Error_Handler(void) { __disable_irq(); while (1) {} }

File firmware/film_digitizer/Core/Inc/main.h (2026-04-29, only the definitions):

#define B1_Pin GPIO_PIN_13
#define B1_GPIO_Port GPIOC
#define USART_TX_Pin GPIO_PIN_2
#define USART_TX_GPIO_Port GPIOA
#define USART_RX_Pin GPIO_PIN_3
#define USART_RX_GPIO_Port GPIOA
#define LD2_Pin GPIO_PIN_5
#define LD2_GPIO_Port GPIOA
#define STEP_Y_PIN_Pin GPIO_PIN_7
#define STEP_Y_PIN_GPIO_Port GPIOC
#define STEP_X_PIN_Pin GPIO_PIN_8
#define STEP_X_PIN_GPIO_Port GPIOA
#define DIR_X_PIN_Pin GPIO_PIN_9
#define DIR_X_PIN_GPIO_Port GPIOA
#define DIR_Y_PIN_Pin GPIO_PIN_11
#define DIR_Y_PIN_GPIO_Port GPIOA
#define TMS_Pin GPIO_PIN_13
#define TMS_GPIO_Port GPIOA
#define TCK_Pin GPIO_PIN_14
#define TCK_GPIO_Port GPIOA
#define SWO_Pin GPIO_PIN_3
#define SWO_GPIO_Port GPIOB

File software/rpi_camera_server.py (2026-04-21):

#!/usr/bin/env python3
"""
ECE 445 – Raspberry Pi HQ Camera Server
========================================
Streams a live MJPEG preview to any browser on the LAN, supports
hardware-button and web-triggered full-resolution captures (JPEG + raw DNG),
and runs the Post_Processing_Negative pipeline locally after each capture.

Usage
-----
    python3 rpi_camera_server.py [--port 8080] [--button-pin 17] [--pc-host 192.168.x.x]

Endpoints
---------
    GET  /                    – Web UI  (live preview + capture button + capture gallery)
    GET  /stream              – MJPEG stream (embed as <img src="/stream">)
    POST /capture             – Trigger a still capture; returns capture metadata JSON
    GET  /captures            – JSON list of stored captures
    GET  /captures/<filename> – Download a JPEG or DNG file
    POST /send/<filename>     – Push a stored JPEG to the PC pipeline server
    GET  /status              – Camera + GPIO status JSON

Camera settings
---------------
Still captures use low-ISO settings (AnalogueGain ≈ 1.0 = ISO 100) with
auto-exposure disabled so that noise is minimised.  ExposureTime defaults to
20 000 µs (1/50 s) which is appropriate for a stable backlight; adjust with
--exposure-us.

Post-processing hook
--------------------
After each capture, on_capture() launches the Post_Processing_Negative
pipeline (run_physical_correction.py) in a background thread if the required
calibration files are present in the capture directory:
  - backlight_frame.dng  (or backlight.dng)
  - base_frame.dng
  - reference_layout.json
Results are written to <capture-dir>/processed/.
"""

import argparse
import io
import json
import logging
import os
import subprocess
import sys
import threading
import time
from datetime import datetime
from pathlib import Path

import requests
import RPi.GPIO as GPIO
from flask import Flask, Response, jsonify, render_template_string, request, send_file
from picamera2 import Picamera2
from PIL import Image

# ── Defaults ──────────────────────────────────────────────────────────────────
DEFAULT_PORT        = 8080
DEFAULT_BUTTON_PIN  = 17
DEFAULT_CAPTURE_DIR = Path.home() / "captures"
DEFAULT_PC_HOST     = "http://192.168.1.100:8000"

PREVIEW_SIZE   = (1332, 990)    # binned 4:3 – fast preview
CAPTURE_SIZE   = (4056, 3040)   # full IMX477 resolution
STREAM_QUALITY = 85             # JPEG quality for MJPEG stream

# ── Fixed low-ISO still capture settings ──────────────────────────────────────
# All AE/AWB/NR controls are hard-locked for maximum fidelity DNG captures.
# AnalogueGain 1.0 = ISO 100 (minimum sensor gain, minimum noise floor).
# ColourGains (1.0, 1.0) locks R/B channel gains; rawpy reads the real WB from DNG metadata.
# NoiseReductionMode 0 disables all in-camera NR so the RAW data is unmodified.
# ExposureTime 50 000 µs (1/20 s) — longer exposure improves SNR under backlight.
STILL_ANALOGUE_GAIN  = 1.0          # ISO 100 — never raise; more gain = more noise
STILL_EXPOSURE_US    = 50_000       # 1/20 s; override with --exposure-us
STILL_AWB_ENABLE     = False        # AWB off — rawpy derives WB from DNG metadata
STILL_COLOUR_GAINS   = (1.0, 1.0)  # neutral R/B gains; no digital colour shift
STILL_NR_MODE        = 0            # 0 = off; keeps RAW data unprocessed

# ── Pipeline directories ───────────────────────────────────────────────────────
# Resolved after arg parsing; set here so the module-level type is clear.
_PIPELINE_SCRIPT: Path | None = None   # absolute path to run_physical_correction.py

logging.basicConfig(level=logging.INFO, format="%(asctime)s [%(levelname)s] %(message)s")
log = logging.getLogger(__name__)

# ── Flask app ─────────────────────────────────────────────────────────────────
app = Flask(__name__)

# ── Shared state ─────────────────────────────────────────────────────────────
_frame_lock    = threading.Lock()
_latest_frame: bytes | None = None
_camera_ready  = threading.Event()
_capture_lock  = threading.Lock()
_capture_dir: Path = DEFAULT_CAPTURE_DIR
_pc_host: str  = DEFAULT_PC_HOST
_picam2: Picamera2 | None = None
_still_config  = None
_still_exposure_us: int = STILL_EXPOSURE_US

# ── Dev-mode state ────────────────────────────────────────────────────────────
_dev_roles: dict = {"base": None, "backlight": None, "film": None}
_dev_roi: list | None = None          # [x0, y0, x1, y1] full-res pixels
_dev_pipeline: dict = {
    "status": "idle",   # idle | running | done | error
    "log": [],
    "images": [],
    "returncode": None,
    "params": {},
}
_dev_lock = threading.Lock()
_processed_dir: Path = DEFAULT_CAPTURE_DIR / "processed" / "_none_"  # replaced per run
_dev_stop_event = threading.Event()   # set to request pipeline abort
_dev_proc: subprocess.Popen | None = None  # current pipeline subprocess


# ── Camera thread ─────────────────────────────────────────────────────────────

def camera_worker():
    """Background thread: continuous preview in video mode."""
    global _latest_frame, _picam2, _still_config

    picam2 = Picamera2()

    video_cfg = picam2.create_video_configuration(
        main={"size": PREVIEW_SIZE, "format": "RGB888"},
        controls={"FrameRate": 30},
    )
    # Still configuration: full sensor resolution + RAW DNG.
    # Low-ISO controls are injected here so they take effect the moment the
    # camera switches to still mode, before the shutter fires.
    still_cfg = picam2.create_still_configuration(
        main={"size": CAPTURE_SIZE},
        raw={"size": picam2.sensor_resolution},
        controls={
            "AeEnable":            False,
            "AwbEnable":           STILL_AWB_ENABLE,
            "AnalogueGain":        STILL_ANALOGUE_GAIN,
            "ExposureTime":        _still_exposure_us,
            "ColourGains":         STILL_COLOUR_GAINS,
            "NoiseReductionMode":  STILL_NR_MODE,
        },
    )
    picam2.configure(video_cfg)
    picam2.start()
    _picam2 = picam2
    _still_config = still_cfg
    _camera_ready.set()
    log.info(
        "Camera started – preview %dx%d  capture %dx%d  ISO~%.0f  exp=%dµs  NR=off  ColourGains=%s",
        *PREVIEW_SIZE, *CAPTURE_SIZE,
        STILL_ANALOGUE_GAIN * 100, _still_exposure_us, STILL_COLOUR_GAINS,
    )

    try:
        while True:
            if _capture_lock.locked():
                time.sleep(0.05)
                continue
            arr = picam2.capture_array("main")
            img = Image.fromarray(arr)
            buf = io.BytesIO()
            img.save(buf, format="JPEG", quality=STREAM_QUALITY)
            with _frame_lock:
                _latest_frame = buf.getvalue()
    finally:
        picam2.stop()
        picam2.close()


# ── Capture logic ─────────────────────────────────────────────────────────────
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

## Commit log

2026-02-25 Add portable_film_pcb_v1 KiCad project & gerbers
    Import new PCB design directory portable_film_pcb_v1: adds KiCad project files (.kicad_pcb, .kicad_sch, .kicad_pro, .kicad_prl, .kicad_dru), Gerber outputs and .gbrjob, PDF fabrication drawing, a lar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
    [portable_film_pcb-B_Cu.gbr, portable_film_pcb-B_Mask.gbr, portable_film_pcb-B_Paste.gbr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]
2026-03-08 Integrate film processing pipeline into web scan flow
2026-03-08 Add 40-tile negative sample dataset for integration demo
    [manifest.csv]
2026-04-18 Initial commit for stm32CubeIDE project
2026-04-20 2-axis motor control
2026-04-21 Add RPi camera server with developer mode UI
    - MJPEG live stream, DNG+JPEG capture at ISO 100 / 1/20s, AWB fix after capture
    - Developer mode UI (/dev): frame role assignment (base/backlight/film), canvas
    ROI crop tool, per-run pipeline trigger with live log streaming
    - Pipeline stage diagram: 8 connected stages with collapsible thumbnails,
    large final result on completion, lightbox on click
    - Per-run timestamped output dirs (processed/run_YYYYMMDD_HHMMSS/) so previous
    results never bleed into the current diagram
    - Parameter panel: flat-field, dye unmix, inversion gains, Stage 10 color
    reference (matrix preset + 4 strengths), Stage 4 final trim (exposure, contrast,
    black/white poin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
    [rpi_camera_server.py]
2026-04-23 Add raw pipeline, Pi camera integration, and physical negative processing
    - orchestrator.py: add process_raw_image() with bounded agent loop over
    flat-field/film-characterization/density-inversion/render-refinement;
    auto-route RAW inputs (.dng/.arw/etc.) and batch RAW directories;
    new --flat/--leader/--frame CLI args for single-frame mode
    - film_characterization.py: fix leader calibration fallback when
    D-max is implausibly high (>4.0); fall back to scene-based estimate
    with zero-confidence guard instead of trusting bad leader data
    - Post_Processing_Negative/: full RAW-first physical negative pipeline
    (flat-field, Bayer ingest, density-space dye unmixing, perceptual
    tone, color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

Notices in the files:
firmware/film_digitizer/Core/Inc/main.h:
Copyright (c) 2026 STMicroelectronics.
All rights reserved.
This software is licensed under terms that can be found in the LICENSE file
